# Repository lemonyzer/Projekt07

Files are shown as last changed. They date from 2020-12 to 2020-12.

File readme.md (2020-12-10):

# Playstation 2 Controller (Digital & Analog) am PIC16F84A 
## mit Zustandsausgabe über MAX7219 LED-Matrix 

### Videos
Projekt07 - PS2 Controller @ PIC16F84A with MAX7219 (https://www.youtube.com/embed/H5jBCrzZ8P4?mute=1;autoplay=1)
Projekt07 - PS2 Controller @ PIC16F84A (https://www.youtube.com/embed/TfXMUS_N8tY?mute=1;autoplay=1)

### PlayStation 2 Controller
<p>
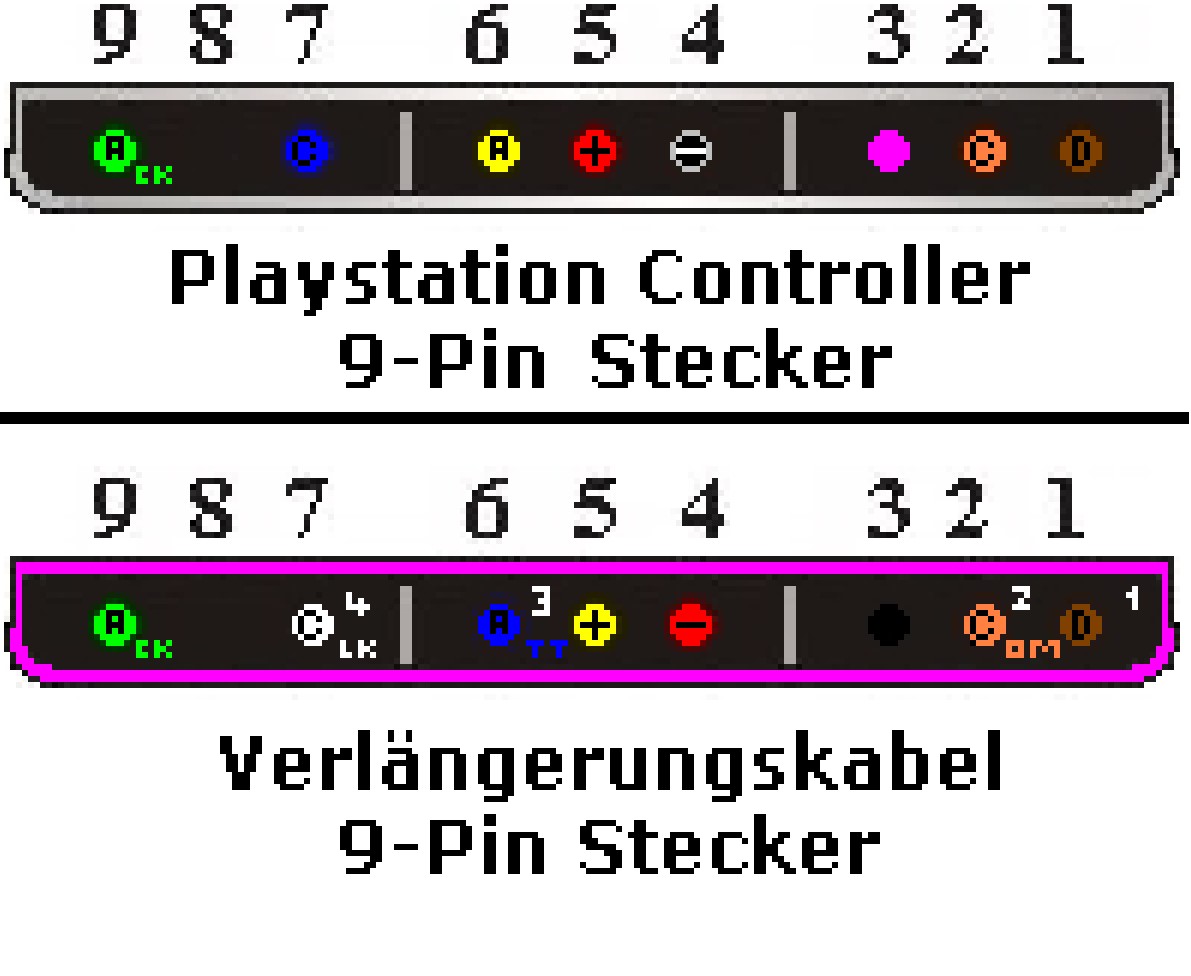
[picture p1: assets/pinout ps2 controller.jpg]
    <br><br>
    <ol>
        <li><p style="margin-bottom: 0cm; text-decoration: none;"><b><font color="#ff0000">(Ausgang)</font>	<font color="#00ff00">DATA</font></b>, 8-bit, serieller Transfer</p>
            <p style="margin-bottom: 0cm; text-decoration: none;">-bei negativer	Flanke von CLOCK</p></li>
        <li><p style="margin-bottom: 0cm; text-decoration: none;"><b><font color="#ff0000">(Eingang)</font>	<font color="#b3b3b3">COMMAND</font></b>, 8-bit, serieller Transfer</p>
            <p style="margin-bottom: 0cm; text-decoration: none;">-bei negativer	Flanke von CLOCK</p></li>
        <li><p style="margin-bottom: 0cm; text-decoration: none;"><i>Nicht	belegt</i></p></li>
        <li><p style="margin-bottom: 0cm; text-decoration: none;"><b>(Eingang)	<font color="#280099">GND</font> - </b>Pin an Masse</p></li>
        <li><p style="margin-bottom: 0cm; text-decoration: none;"><b>(Eingang)	<font color="#ffff00">VCC</font> - </b>Pin zur +5V Spannungsquelle</p></li>
        <li><p style="margin-bottom: 0cm; text-decoration: none;"><b><font color="#ff0000">(Eingang)</font>	<font color="#ff0000">ATT</font> -</b> bevor der Controller Daten	erhält, muss hier 0V (Masse) anliegen.</p></li>
        <li><p style="margin-bottom: 0cm; text-decoration: none;"><b><font color="#ff0000">(Eingang)</font>	CLOCK -</b> zur synchronisierten Übertragung</p></li>
        <li><p style="margin-bottom: 0cm; text-decoration: none;"><i>Nicht	belegt</i></p></li>
        <li><p style="margin-bottom: 0cm; text-decoration: none;"><b>(Ausgang)	<font color="#cc6633">ACK</font> - </b>sendet ein Signal, wenn ein	Befehl an Pin 2 angekommen ist</p></li>
    </ol>
    <p style="margin-bottom: 0cm; text-decoration: none;"><font color="#ff0000"><b>ROT</b><font color="#000000"> markierte Ein- oder Ausgänge sind direkt am PIC angeschlossen.</font></font></p>
    <p style="margin-bottom: 0cm; text-decoration: none;"><br></p>
</p>

### Schaltplan
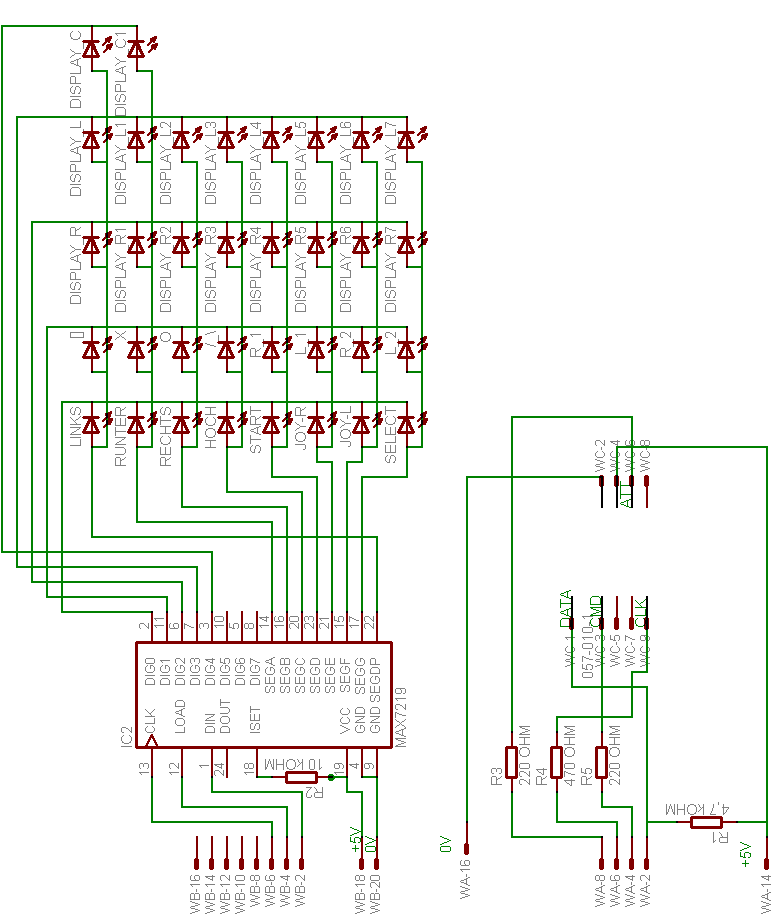
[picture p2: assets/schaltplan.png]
Schaltplan
   

### Platinen Layout
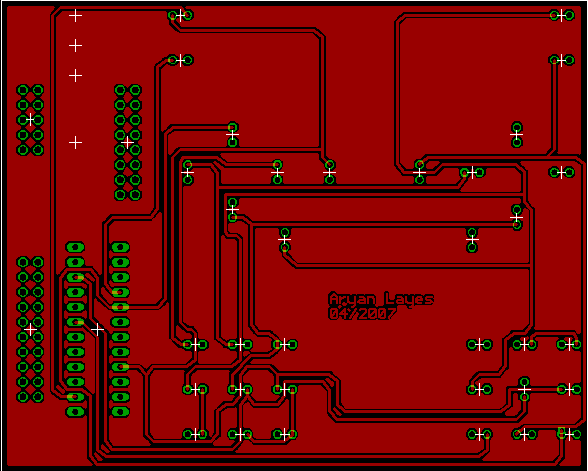
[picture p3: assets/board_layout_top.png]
Layout Top
   
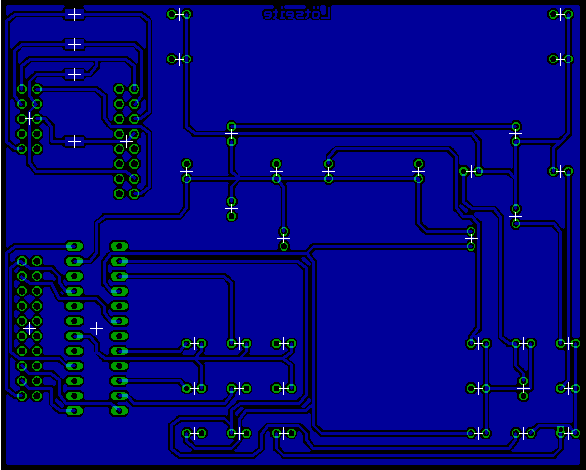
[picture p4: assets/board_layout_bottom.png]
Layout Bottom
   

### Bestückungsplan
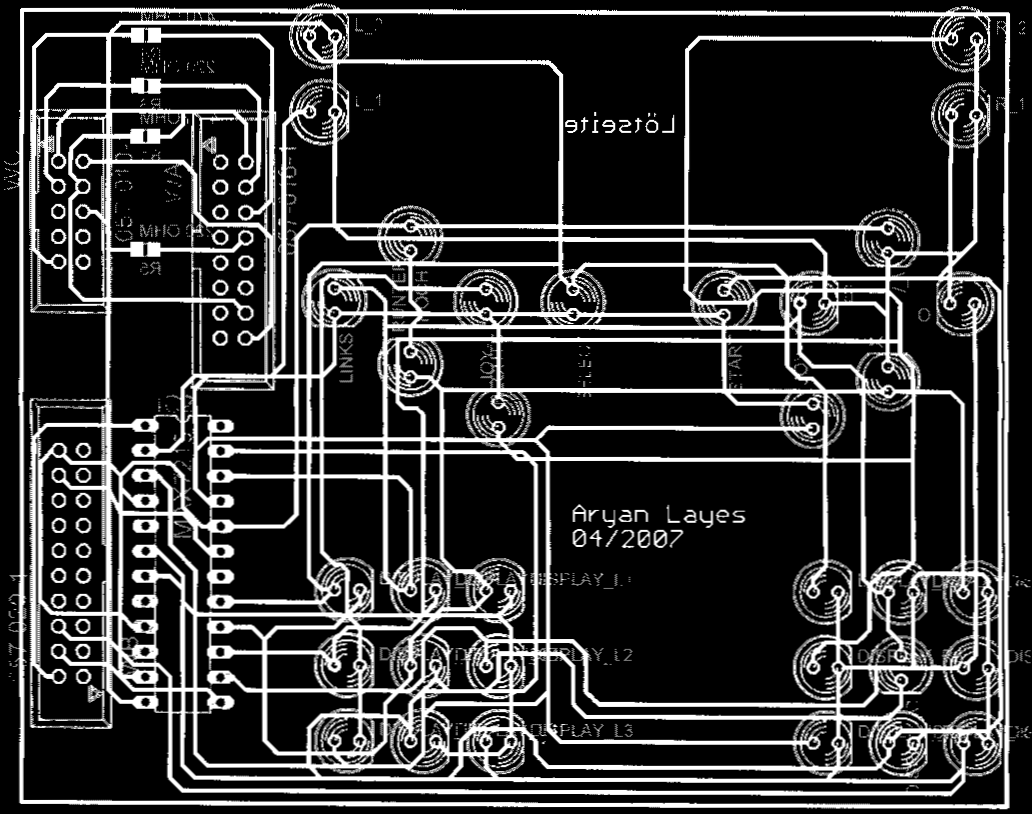
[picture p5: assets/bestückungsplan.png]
Bestückungsplan
   

### Flowcharts
<details> 
  <summary>V5: Flowcharts aus der Dokumentation </summary>
   <p>
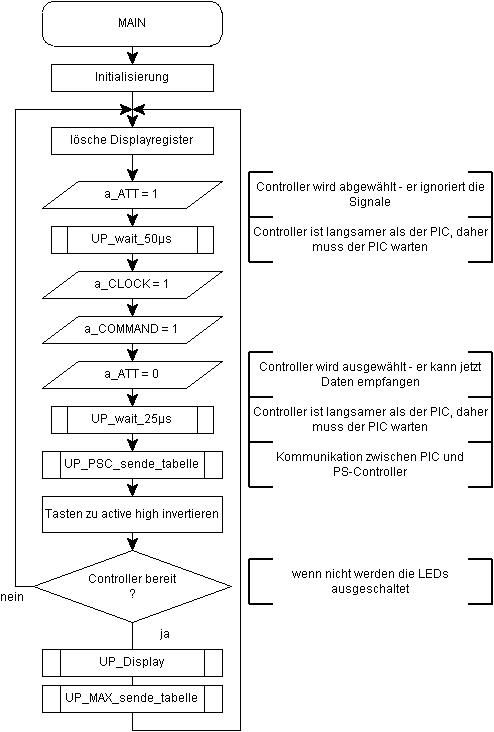
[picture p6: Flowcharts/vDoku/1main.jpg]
         
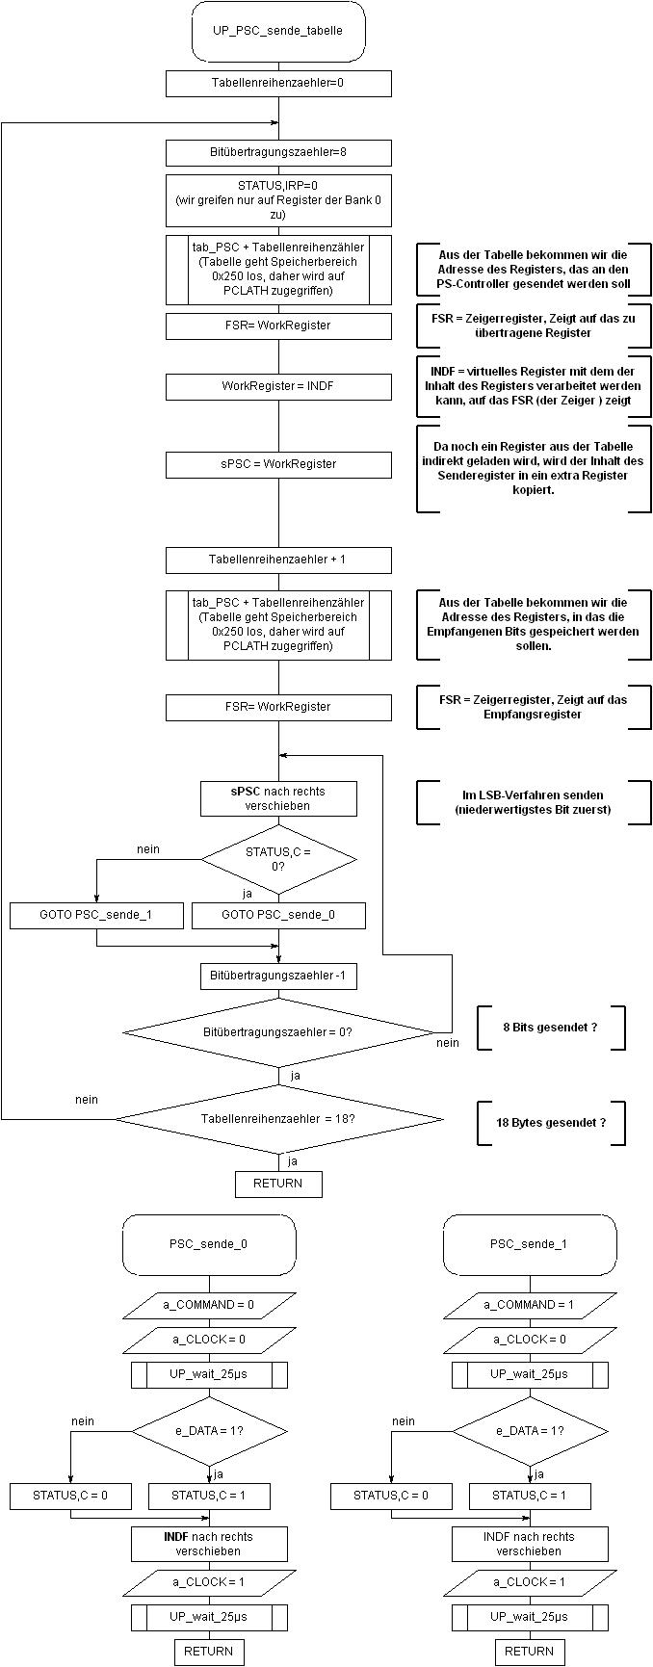
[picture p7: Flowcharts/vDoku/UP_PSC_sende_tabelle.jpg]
         
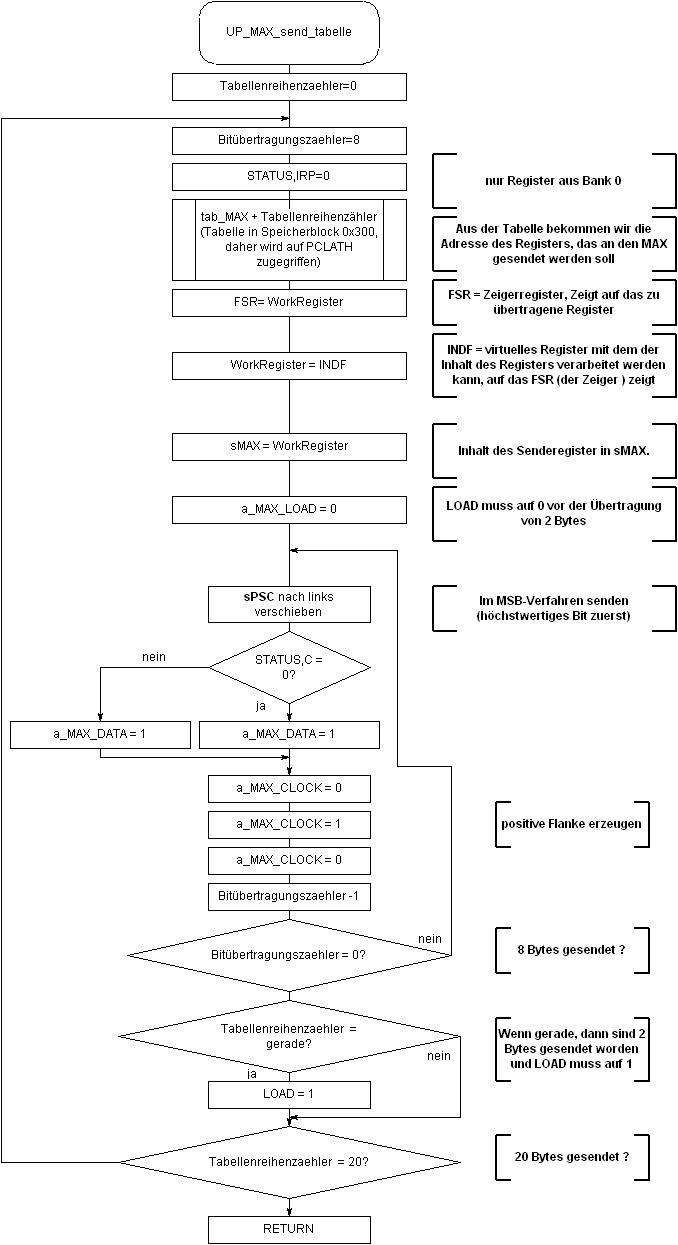
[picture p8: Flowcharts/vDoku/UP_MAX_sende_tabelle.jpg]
         
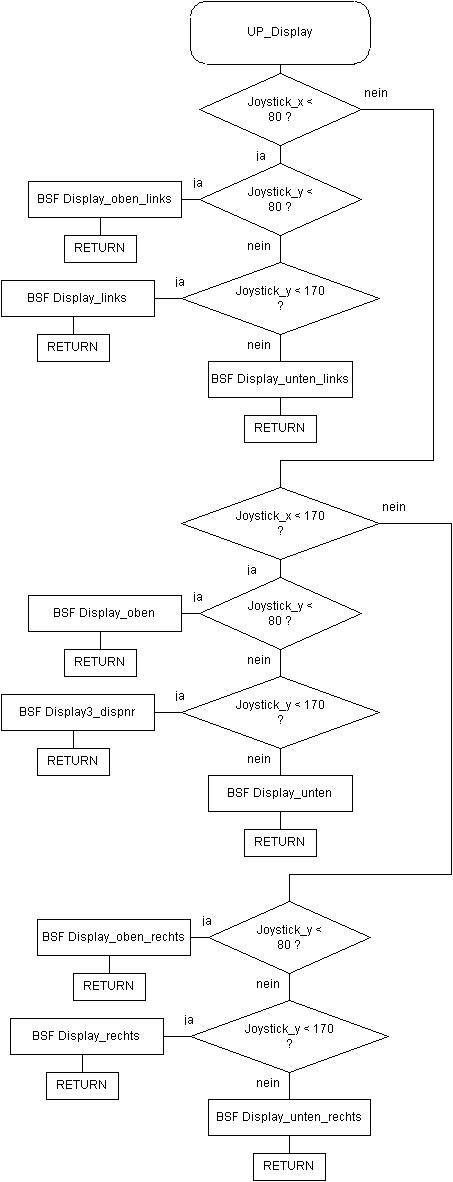
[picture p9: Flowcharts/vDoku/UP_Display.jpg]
         
    </p>
</details>

<details> 
  <summary>V4: Flowcharts </summary>
   <p>
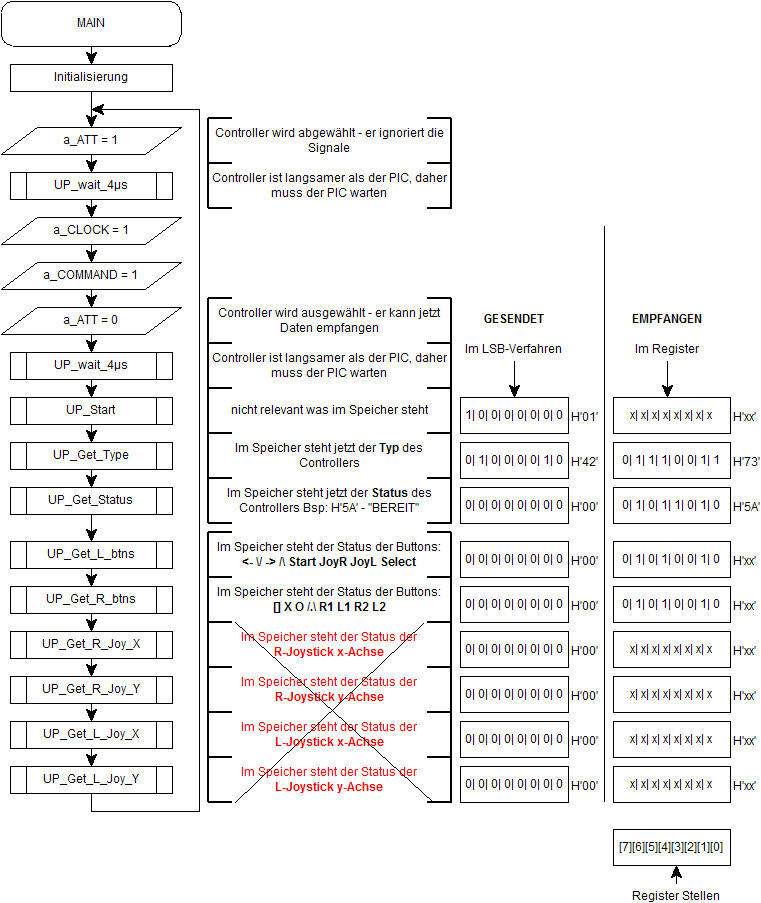
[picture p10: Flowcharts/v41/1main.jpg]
         
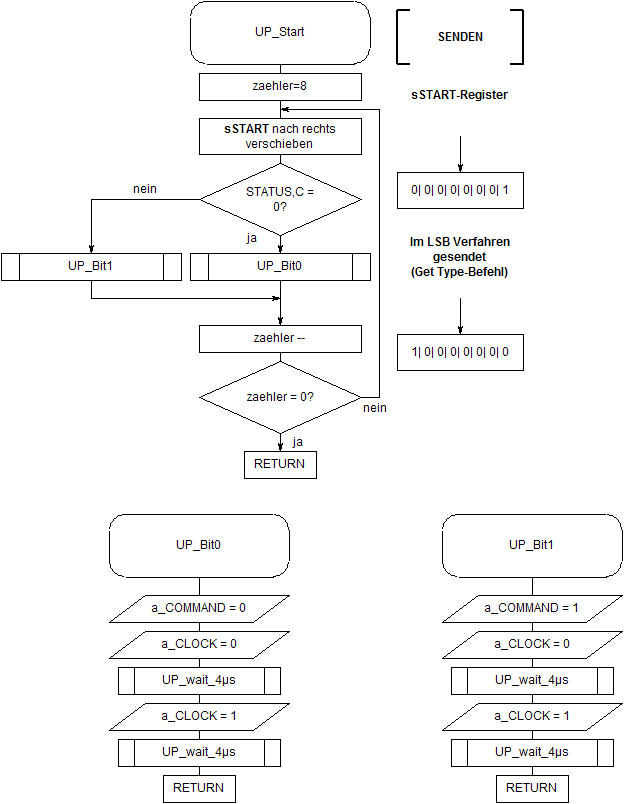
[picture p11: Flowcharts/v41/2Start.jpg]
         
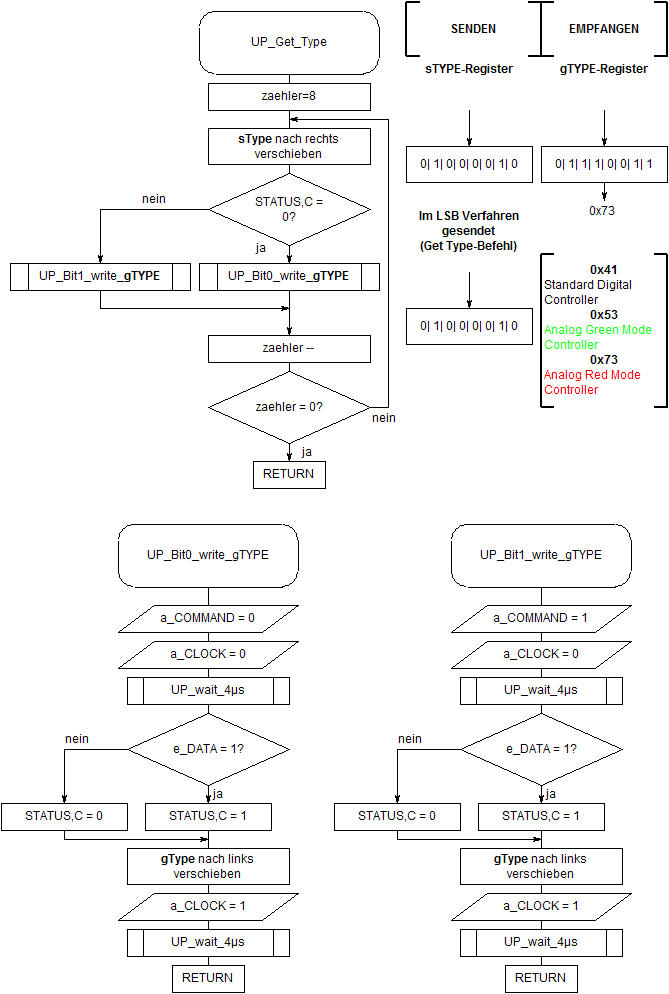
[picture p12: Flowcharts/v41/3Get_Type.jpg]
         
         
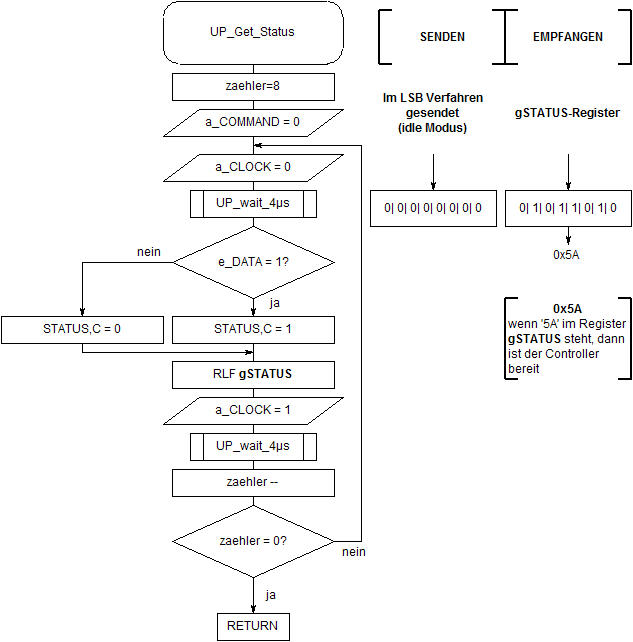
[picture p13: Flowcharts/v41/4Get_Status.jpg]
         
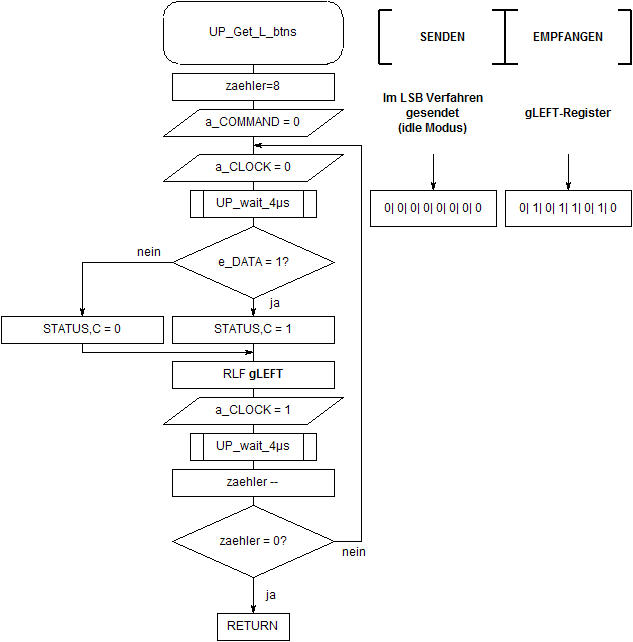
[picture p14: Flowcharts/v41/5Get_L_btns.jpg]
         
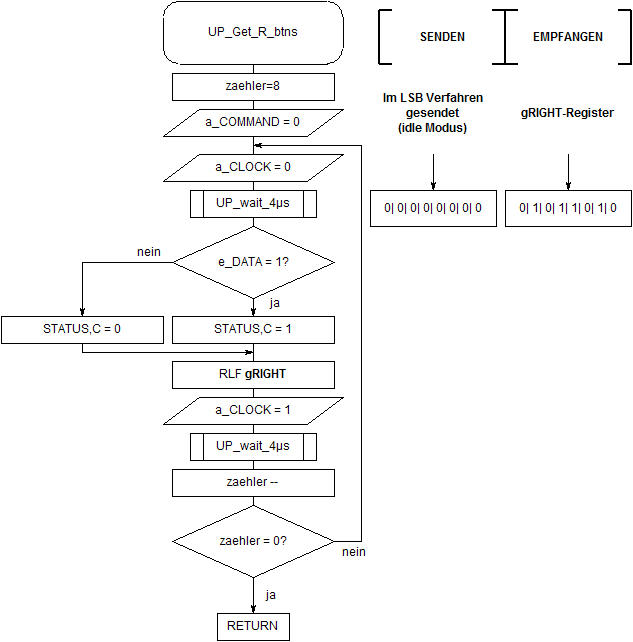
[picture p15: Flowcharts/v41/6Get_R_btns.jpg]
         
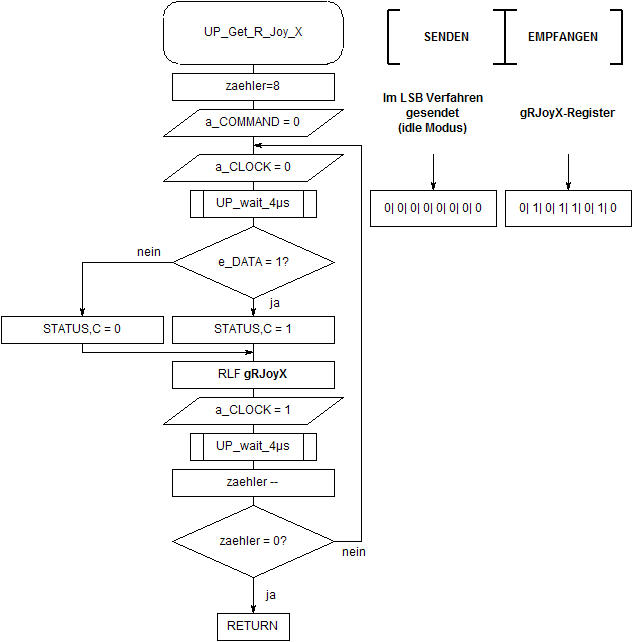
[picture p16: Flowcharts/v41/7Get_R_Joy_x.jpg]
         
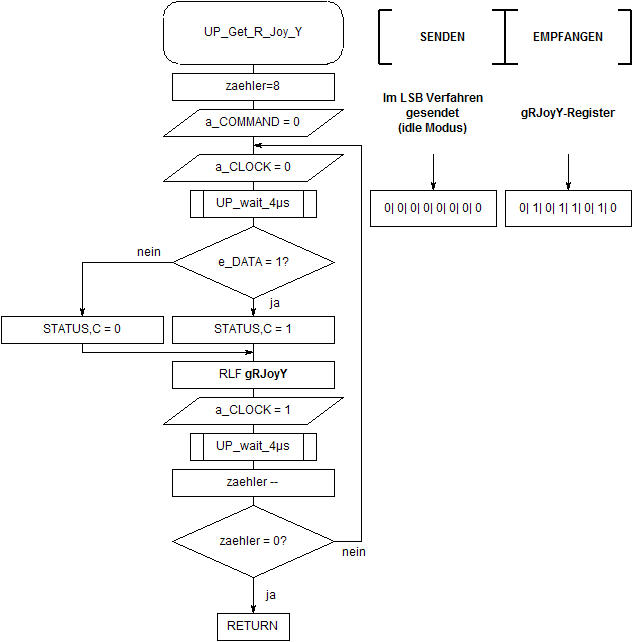
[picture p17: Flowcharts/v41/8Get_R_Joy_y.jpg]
         
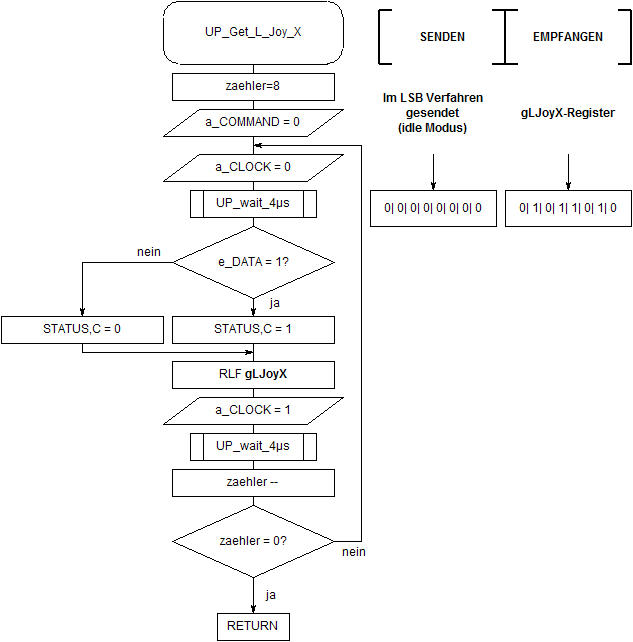
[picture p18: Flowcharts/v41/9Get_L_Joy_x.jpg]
         
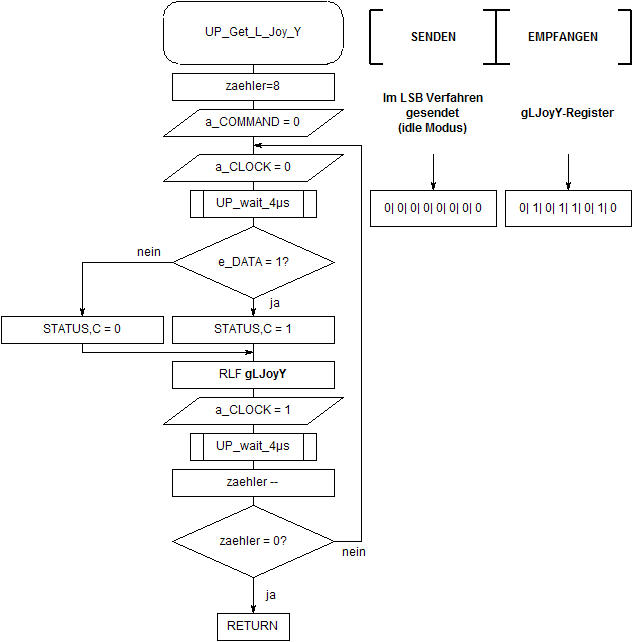
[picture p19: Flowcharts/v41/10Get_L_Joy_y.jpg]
        
    </p>
</details>

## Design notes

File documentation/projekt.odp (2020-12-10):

## Abschlussprojekt - ATINF

Aryan Layes

## Projekt

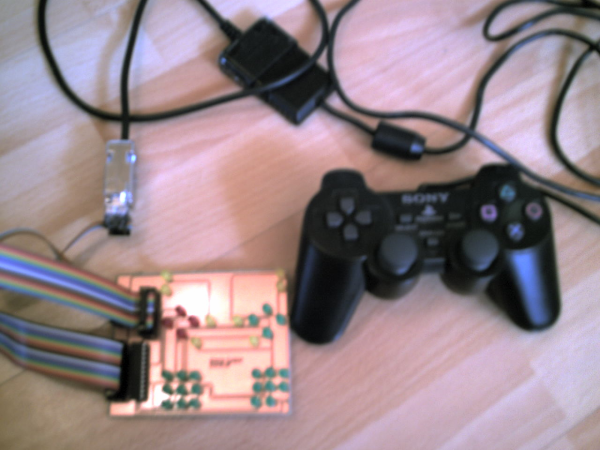
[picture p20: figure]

## Projektbeschreibung

- Der PS-Controller ist an PORTA des PIC's angeschlossen
- Der PIC fragt die Zustände des Controller's ab
- Ausgabe Variante 1:
  - Die Abgefragten Zustände werden über 8 LED's an PORTB ausgegeben
- Ausgabe Variante 2:
  - Die Abgefragten Zustände werden über einen MAX7219 LED Display Treiber ausgegeben

## PS-Controller Schnittstelle

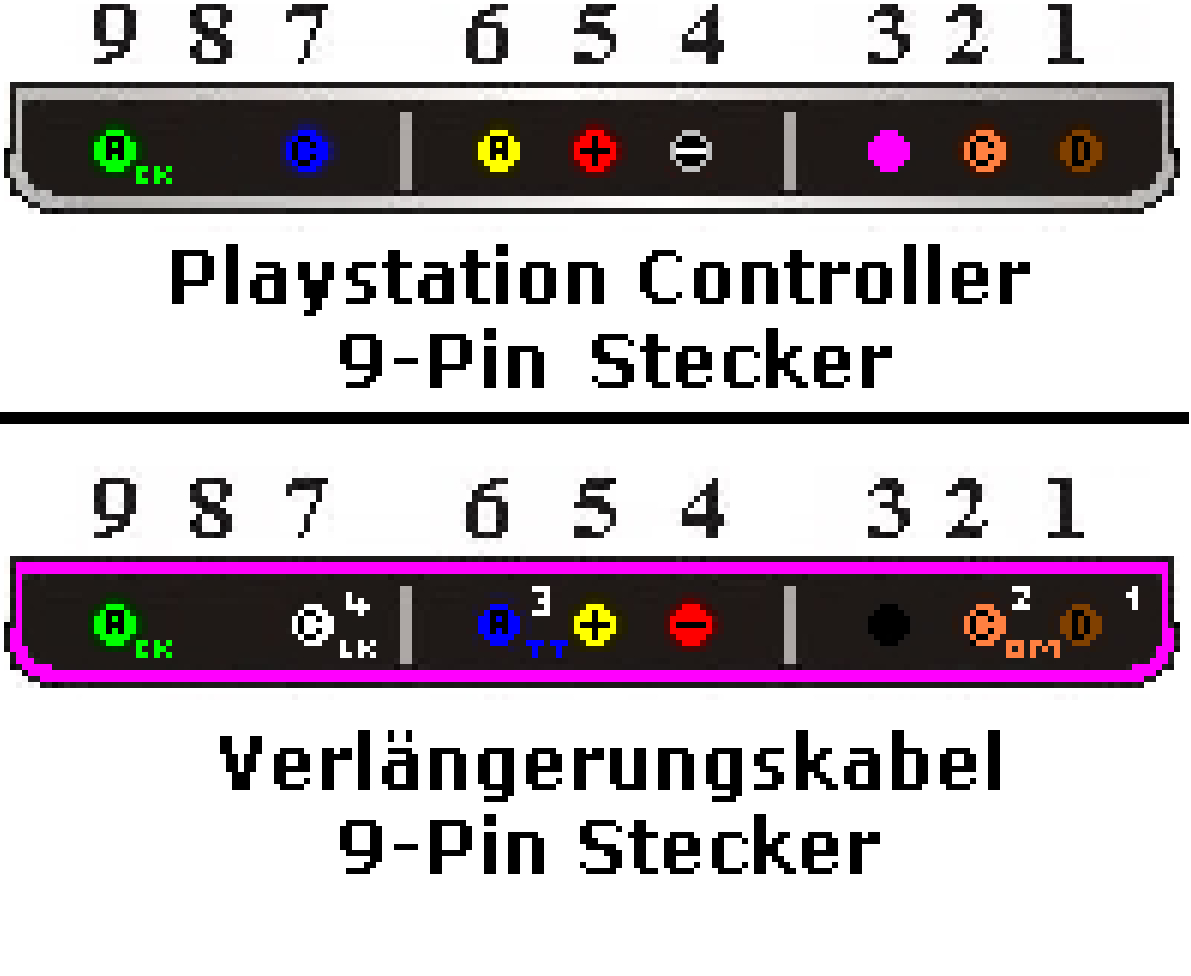
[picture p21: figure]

- 1. (Ausgang) DATA, serielle Datenübertragung - bei negativer Flanke von CLOCK sendet der Controller ein Bit über die DATA Leitung - die Datenübertragung beginnt mit dem niederwertigsten Bit ( LSB-Verfahren ).
- 2. (Eingang) COMMAND, serielle Datenübertragung - bei negativer Flanke von CLOCK ließt der Controller das Bit auf der COMMAND Leitung
- 3. Nicht belegt

## PS-Controller Schnittstelle

- 4. (Eingang) GND - Pin an Masse
- 5. (Eingang) VCC - Pin zur +5V Spannungsquelle
- 6. (Eingang) ATT - bevor der Controller Daten erhält, muss hier 0V (Masse) anliegen.
- 7. (Eingang) CLOCK - zur synchronisierten Übertragung
- 8. Nicht belegt
- 9. (Ausgang) ACK - sendet ein Signal, wenn ein Byte über COMMAND angekommen ist

## PS-Controller Kommunikation

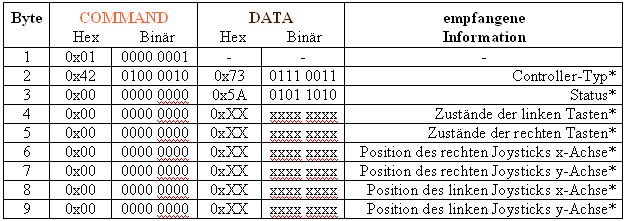
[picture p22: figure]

## Controller-Typ

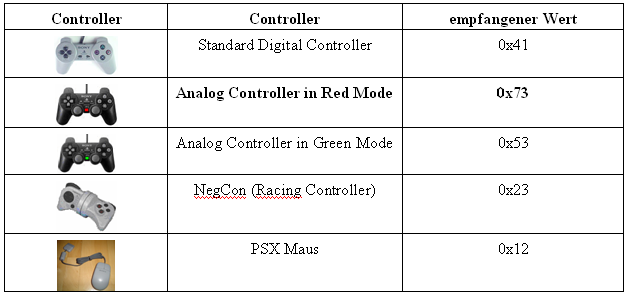
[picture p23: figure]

## Status

- Wenn das empfangene Byte ungleich 01011010 ist, ist der Controller nicht bereit oder sogar defekt! Die Zustände der Tasten, die in der folgenden Übertragung empfangen werden, sind wahrscheinlich unbrauchbar.

## Zustände der Tasten

- Allgemeines zum Zustand der Tasten:
- Wenn eine Taste gedrückt ist, sendet der Controller an der Stelle eine 0. Im englischen heißt das, dass die Tasten „active low“ sind !
- *linke Tasten
- Zu den linken Tasten gehören:
- Die Zustände der gelb markierten Tasten sind bei einem Standart Digital Controller, der keine Joysticks hat, immer auf 1.
- *rechte Tasten
- Zu den rechten Tasten gehören:

## MAX7219 – LED Display Treiber Ein- und Ausgänge

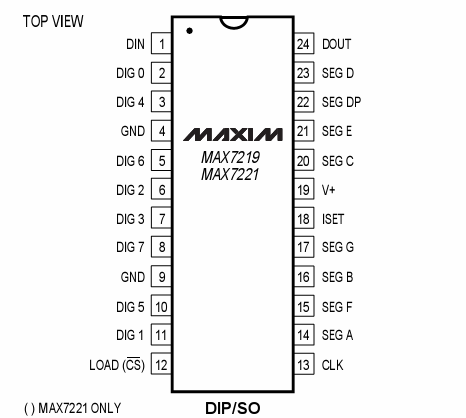
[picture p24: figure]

- Spannungs- und Stromversorgung
- 19. V+ (+5V) Spannungsquelle
- 4 & 9. GND
- 5. ISET Helligkeitsregelung der LED Anzeige über extern geschalteter Widerstand.

## MAX7219 – LED Display Treiber Ein- und Ausgänge

- I/O Kommunikation/Steuerung des MAX-IC’s
- 1. (Eingang) DIN, serielle Datenübertragung
- - die Datenübertragung beginnt mit dem letzten Bit 15 ( MSB-Verfahren ). - bei positiver Flanke von CLK übernimmt der MAXIM das anstehende Bit an DIN.
- 12. (Eingang) LOAD - die Übertragung beginnt mit dem Schalten von LOAD auf 0V (Masse). Die zwei Bytes werden transferiert und danach wird LOAD wieder auf 1(+5V) geschaltet.
- 13. (Eingang) CLK - zur synchronisierten Übertragung der Bits über DIN

## MAX7219 – LED Display Treiber Ein- und Ausgänge

- LED Steuerung
- 6. (Ausgang) DIG 0 bis DIG 7 – Jede LED wird über dazugehörigen Digitausgang angesteuert, dies geschieht über die Kathoden der LEDs
- 7. (Ausgang) SEG DP - G – Die einzelnen Segmente der Digits werden mit den gleichen Segmenten der anderen Digits verbunden. Zum Beispiel: Anode der SEG DP LED an im Digit 0 ist verbunden mit der Anode der SEG DP LED im Digit 1.

## MAX7219 Steuerung

- Die Steuerung des MAX7219 erfolgt über zwei Byte lange Befehle.
- Das zweite Byte (links) gibt an auf welches Register des MAX7219 zugegriffen wird. Mit dem ersten Byte (rechts) werden die Werte in dem Register festgelegt.
- Die folgende Tabelle aus dem Datenblatt des MAX7219 zeigt welche Register zur Verfügung stehen.

## MAX7219 Steuerung

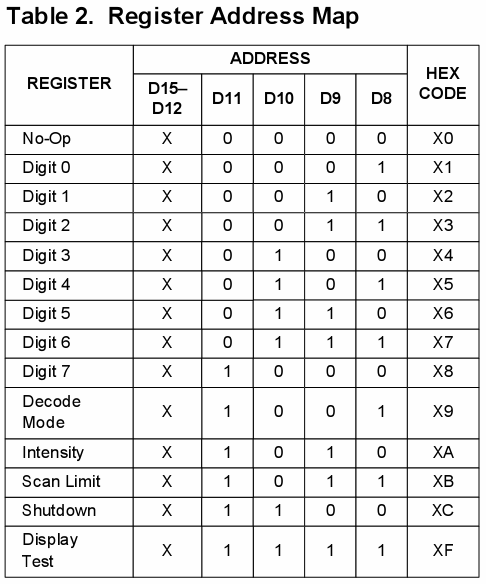
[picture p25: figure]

## MAX7219 Register

- Digit 0-7:
- speichert die Zustände der Segmente
- Decode Mode:
- Der MAX7219 wurde so entwickelt, dass er neben der ganz normalen Ausgabe der Digits einen integrierten BCD-Decoder bereitstellt. Auf diesen werde ich in meiner Dokumentation aber nicht eingehen.
- Intensity:
- Auch hier gibt es eine spezielle Funktion des Display Treibers. Die Helligkeitssteuerung kann über den ISET-Eingang, oder durch dieses Register erfolgen. Da ich in meinem Projekt keine Helligkeitssteuerung verwende und das Datenblatt die Informationen zu diesem Feature beinhaltet, gehe ich nicht näher darauf ein.

## MAX7219 Register

- Scan Limit:
- Über dieses Register lässt sich einstellen wie viele Digits genutzt werden. Nicht benutzte Digits sollten nicht aktiviert werden, da diese die Helligkeit der Anzeige „dimmen“ würden.
- Shutdown:
- Mit diesem Register wird die Anzeige ein- und ausgeschaltet.
- Shutdown:
- Mit diesem Register kann die Anzeige geprüft werden. Im Testmodus sollten alle LEDs an sein.

## Flussdiagramme

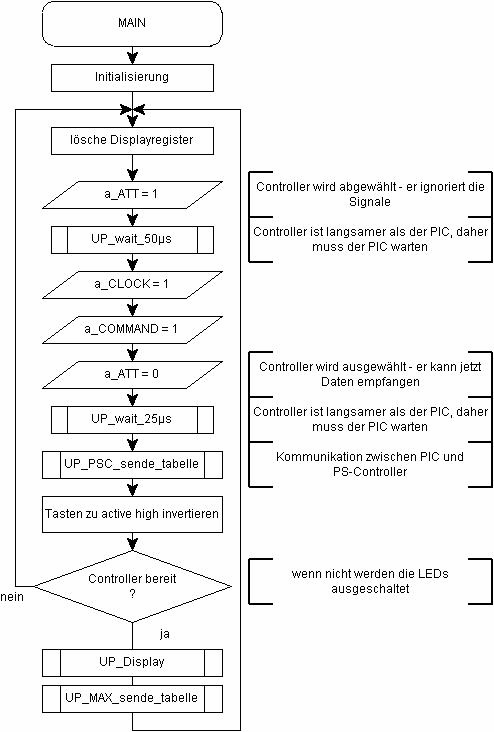
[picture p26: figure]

- Main

## Flussdiagramme

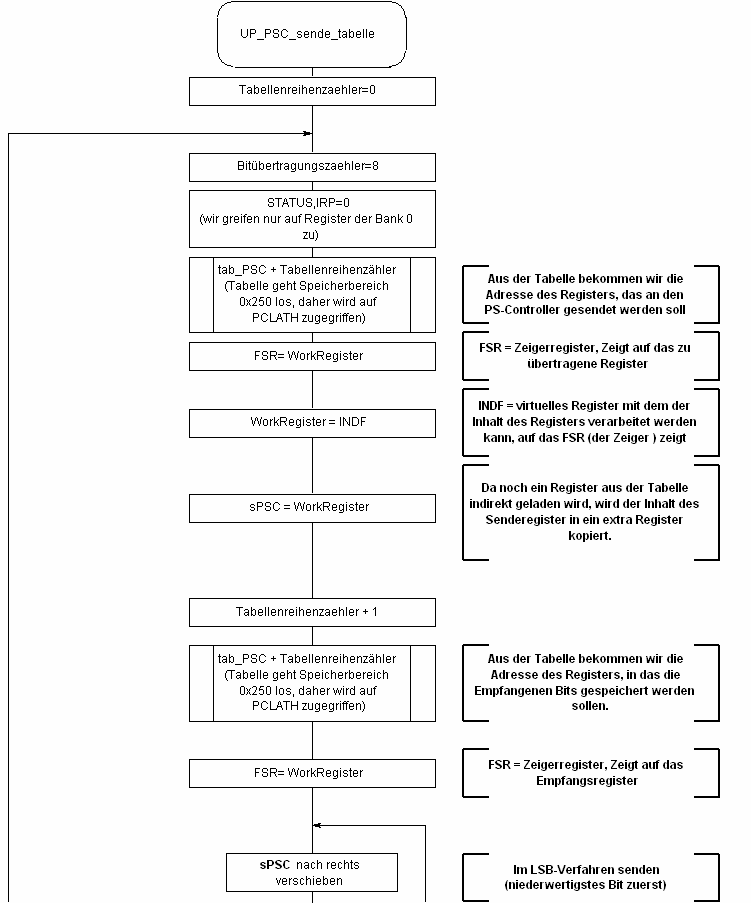
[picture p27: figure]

- UP_PSC_sende_tabelle Teil 1

## Flussdiagramme

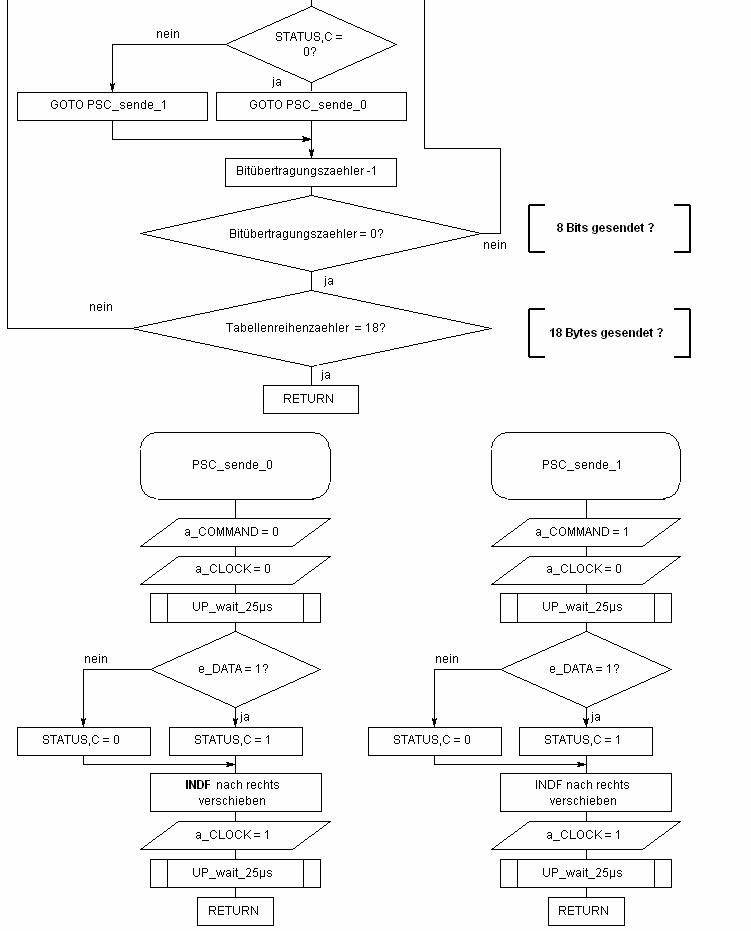
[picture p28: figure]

- UP_PSC_sende_tabelle Teil 2

## Flussdiagramme

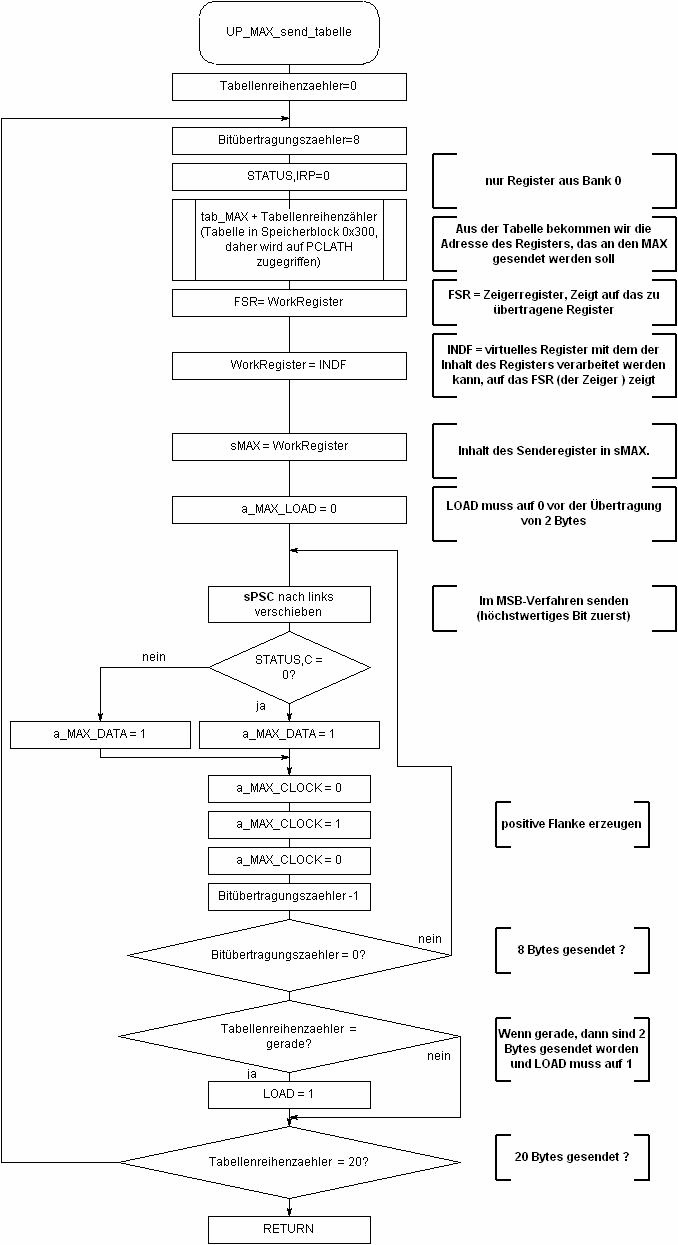
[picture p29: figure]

- UP_MAX_sende_tabelle

## Flussdiagramme

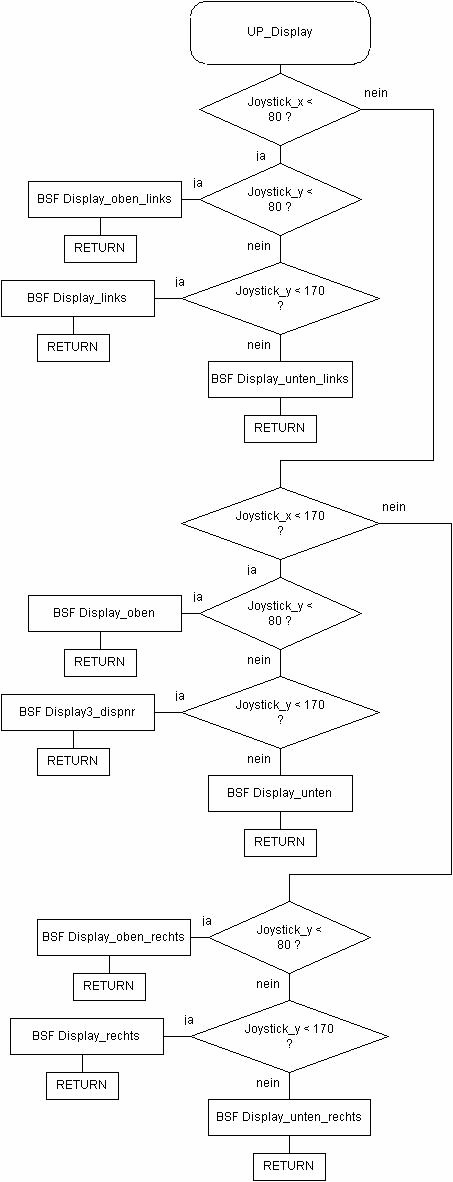
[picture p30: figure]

- UP_Display

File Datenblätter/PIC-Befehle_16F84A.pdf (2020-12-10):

Kurzübersicht über die Assemblerbefehle des PIC16F84A

Sprungbefehle und die Operationen mit Konstanten
ANDLW | k | UND-Verknüpfung des W-Registers mit einer Konstanten
CALL | k | Unterprogrammaufruf
CLRWDT | | Watch-Dog-Timer zurücksetzen
GOTO | k | Sprung zur angegebenen Position im Programm
IORLW | k | ODER-Verknüpfung des W-Registers mit einer Konstanten
MOVLW | k | W-Register mit einer Konstanten laden
RETURN | | Rücksprung aus dem Unterprogramm
RETLW | k | Rücksprung aus dem Unterprogramm mit Konstantenübergabe im W-
| | Register
SLEEP | | Standby-Modus einschalten
XORLW | k | Exklusiv-ODER-Verknüpfung des W-Registers mit einer Konstanten

byteorientierte Befehle
ADDWF | f, d | Addiere W-Register zu einem Register
ANDWF | f, d | UND-Verknüpfung zwischen dem W-Register und einem anderem
| | Register
CLRF | f | Lösche Register
CLRW | | Lösche W-Register
COMF | f, d | Bilde Komplement des Registers
DECF | f, d | Dekrementiere Register
DECFSZ | f, d | Dekrementiere Register und springe bei Null
INCF | f, d | Inkrementiere Register
INCFSZ | f, d | Inkrementiere Register und springe bei Null
IORWF | f, d | ODER-Verknüpfung zwischen W-Register und Register
MOVF | f, d | Registerinhalt kopieren
MOVWF | f, d | W-Register nach Register kopieren
NOP | | Keine Operation
RLF | f, d | Rotiere Register nach links durch Carry-Flag
RRF | f, d | Rotiere Register nach rechts durch Carry-Flag
SUBWF | f, d | Subtrahiere W-Register von Register
SWAPF | f, d | Tausche Bytehälften vom Register
XORWF | f, d | Exklusiv-ODER-Verknüpfung von W-Register und Register

bitorientierte Befehle
BCF | f, b | lösche Bit des Registers
BSF | f, b | setze Bit des Registers
BTFSC | f, b | teste Bit des Registers uns springe wenn gelöscht
BTFSS | f, b | teste Bit des Registers und springe wenn gesetzt
k | Konstante: Wert binär (B'xxxxxxxx'), hexadezimal (H'xx') oder dezimal (D'xx')
f | (symbolische) Adresse des Registers, in dem sich der Operand befindet
d=W | Ergebnis der Operation wird im Arbeitsregister gespeichert
d=F | Ergebnis der Operation wird im Operandenregister gespeichert
b | Nummer des Bits (0-7)

Einige wichtige Register:
Bank 0
TMR0 | 8-bit Real-Time Clock/Counter
PCL | Low Order 8 bits of the Program Counter (PC)
STATUS | IRP | RP1 | RP0 | TO | PD | Z | DC | C
PORTA | - | - | - | RA4/T0CKI | RA3 | RA2 | RA1 | RA0
PORTB | RB7 | RB6 | RB5 | RB4 | RB3 | RB2 | RB1 | RB0
INTCON | GIE | EEIE | T0IE | INTE | RBIE | T0IF | INTF | RBIF
Bank 1
OPTION_REG | RBPU | INTEDG | T0CS | T0SE | PSA | PS2 | PS1 | PS0
TRISA | - | - | - | PORTA Data Direction Register
TRISB | PORTB Data Direction Register

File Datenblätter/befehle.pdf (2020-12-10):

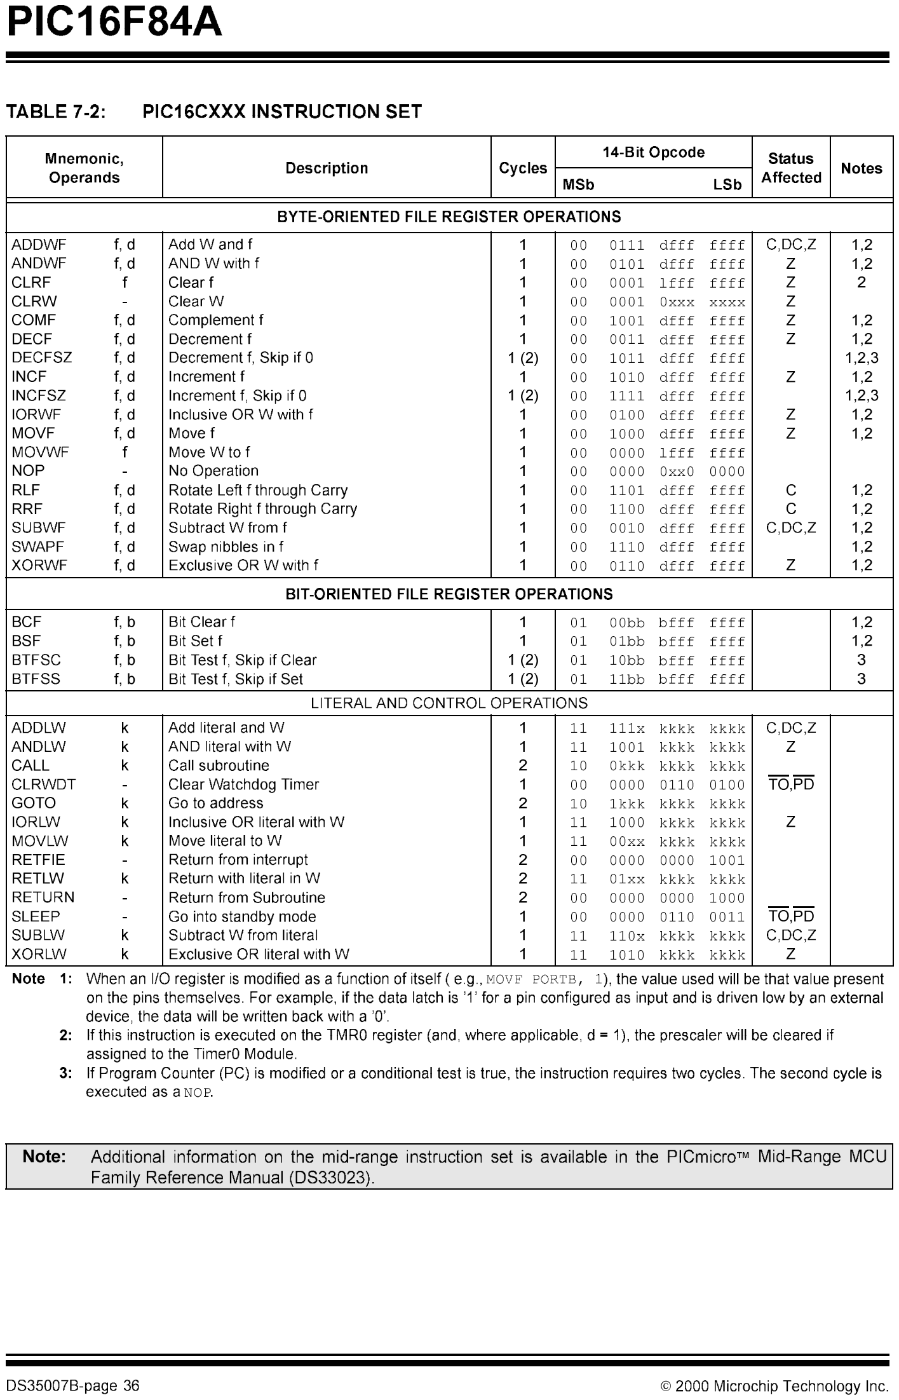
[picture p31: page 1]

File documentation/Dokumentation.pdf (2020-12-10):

## Abschlussprojekt

## „Arbeitsmethoden der technischen Informatik“

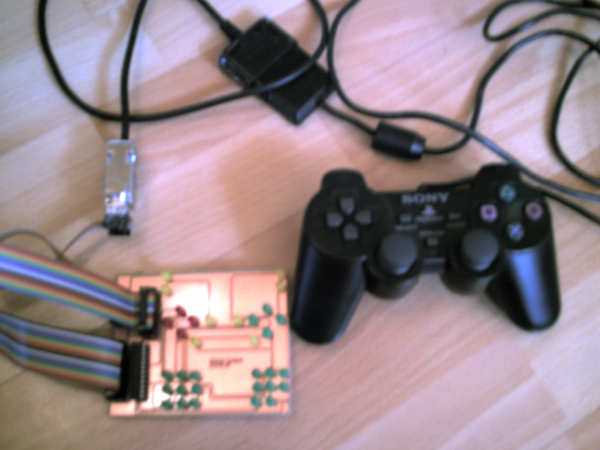
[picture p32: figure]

## Playstation 2 Controller (Digital & Analog) am PIC16F84A mit Zustandsausgabe über MAX7219

## von Aryan Layes

## Inhaltsverzeichnis

## Einleitung

## 1.0 Projektvorgaben 1.1 Projektbeschreibung 1.2 Ziel des Projekts

## Hardware

## 2.0 Schaltplan des PS2-MAX-Boards 2.1 Bestückung / Stückliste 2.2 Die Schnittstelle des Playstation Controllers 2.3 Kommunikations-Protokoll des Playstation Controllers 2.4 MAX7219 I/O 2.5 MAX7219 Steuerung

## Software

## 3.0 Neue Programmiermethoden 3.1 Quellcode 3.2 Flussdiagramme

## Bilanz

## 4.0 Eigene Erfahrungen

## Anhang

## 5.0 Quellen 5.1 Versicherung der Eigenleistung

µC-Projekt | Arbeitmethoden der Informatik | Seite 1 von 35
Aryan Layes | www.Projekt07.dl.am | HBFI05a

## 1.0 Projektvorgaben

Im Fach „Arbeitsmethoden der technischen Informatik“ war es unsere Aufgabe, ein Projekt mit Hilfe der im Unterricht angefertigten PIC-Platine anzufertigen. Es wurden mehrere Projektvorschläge angeboten die mir alle nicht zusagten. Zu erst wollte ich einen eigenen Controller mit Hilfe eines alten PS-Controllers entwickeln, doch Herr Glaser überredete mich den Controller funktionstüchtig zu lassen und mein Projekt auf das

auslesen des Controller mit einer einfachen Anzeige zu beschränken.

### Zeitliche Vorgaben: Für das gesamte Projekt ist ein Zeitrahmen von dem Tag der Projektgenehmigung bis

zum 19.04.07 vorgesehen.

## 1.1 Projektbeschreibung

### Mein Projekt besteht aus der PIC-Platine (bestückt mit einem PIC16F84A), einem

Playstation Controller und einem MAX7219 LED Display Treiber von MAXIM.

### Der Playstation Controller ist über den Wannenstecker SV1 mit dem PIC an PORTA

verbunden.

### Der MAX 7219 Baustein ist über den Wannenstecker SV2 mit dem PIC an PORTB

verbunden.

### Der PIC kommuniziert mit dem PS-Controller und erhält so die Zustände der Tasten und Joysticks. Nachdem er diese Daten erhalten hat, überträgt er sie an den MAX7219

Display Treiber, aus dem Hause MAXIM, um die Zustände anzeigen zu lassen.

## 1.2 Ziel des Projekts

Mein Projekt hat in erster Linie nur das Ziel zu verstehen, wie man mit einem Playstation-Controller kommuniziert um die Zustände der Tasten und Joysticks herauszufinden. Die Zustandsanzeige der Tasten und Joysticks über den MAX-Baustein ist nur durch eigene Interesse und Neugier entstanden. Auf diesem Wissen lassen sich jetzt viele Projekte aufbauen, z.B. ein „kabelloser“ Controller oder das Steuern eines

Roboters mit dem PS-Controller.

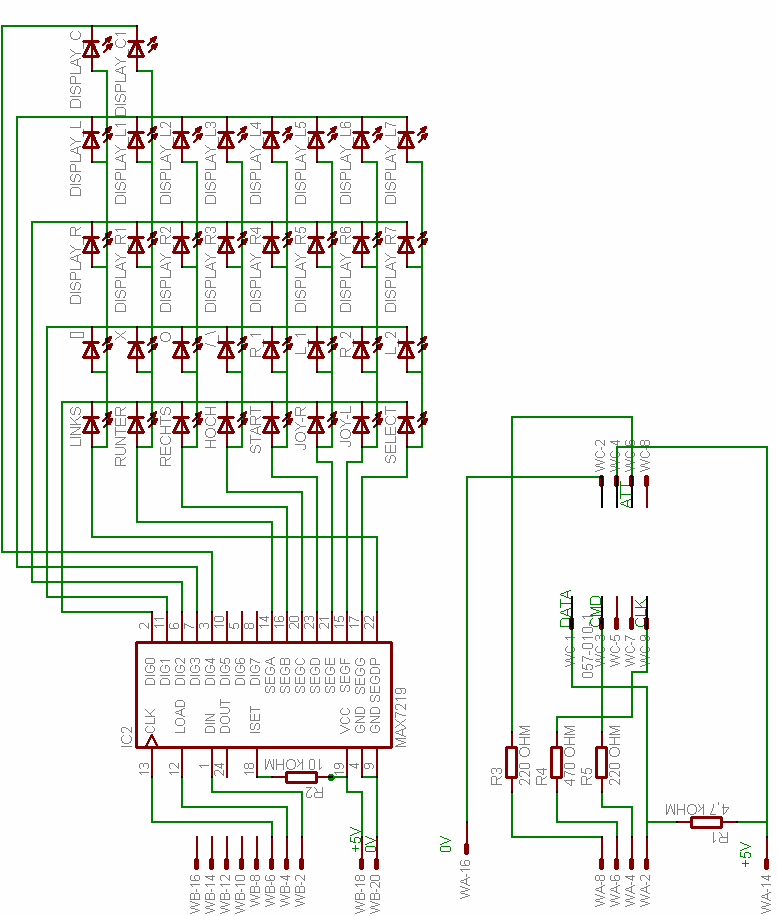
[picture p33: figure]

Aryan Layes | www.Projekt07.dl.am | HBFI05a

## 2.0 Schaltplan des PS2-MAX-Boards

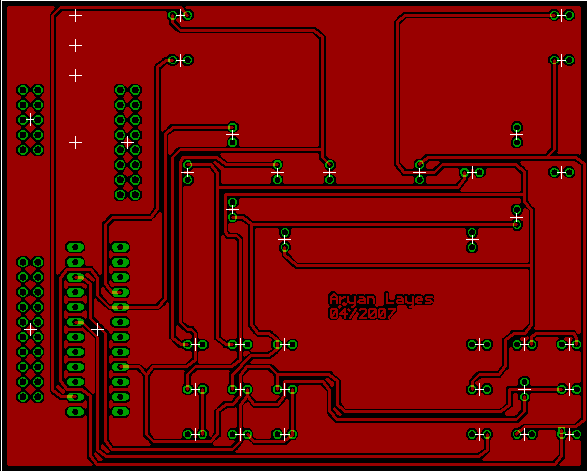
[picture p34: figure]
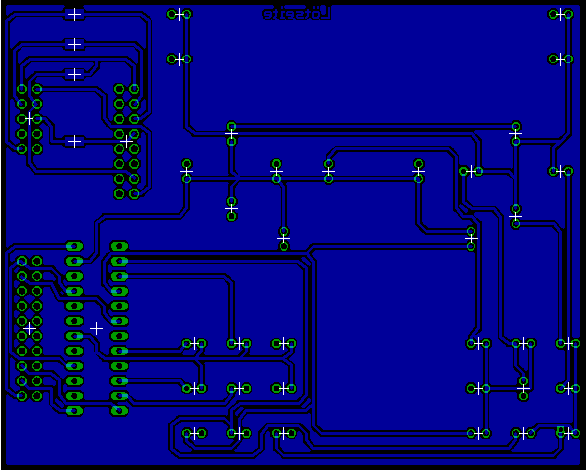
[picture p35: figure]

Aryan Layes | www.Projekt07.dl.am | HBFI05a

## Vorderseite des PSC-MAX-Boards

## Rückseite und damit Lötseite des PSC-MAX-Boards

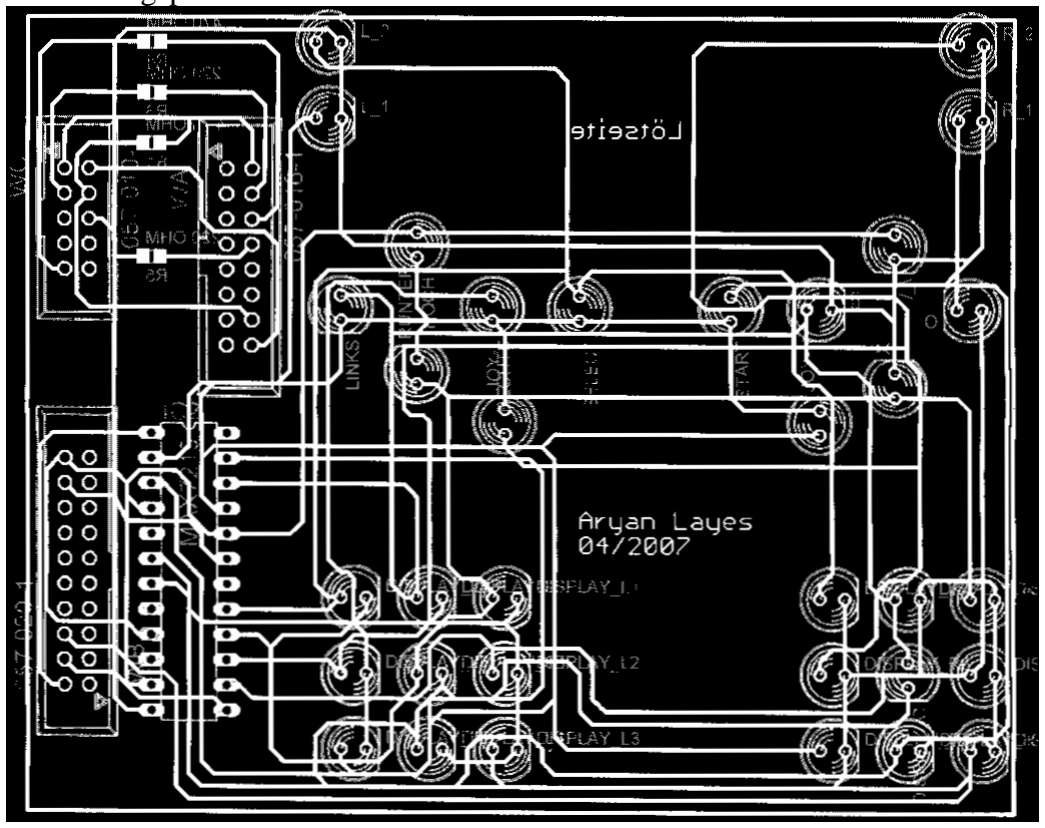
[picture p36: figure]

Aryan Layes | www.Projekt07.dl.am | HBFI05a

## 2.1 Bestückung / Stückliste

Bauteil | Wert
alle LED’s | besitzen einen integrierter Vorwiderstand, der für eine Spannung von 5 Volt vorgesehen ist
R1 | 4,7 kOHM
R2 | 10 kOHM
R3,R5 | 220 OHM
R4 | 470 OHM
R6 | 10 kOHM
IC2 | MAX 7219

## Bestückungsplan

### - In der Schaltung kommen vier verschiedene Widerstandswerte vor:

220 OHM | ROT ROT BRAUN | GOLD
470 OHM | GELB VIOLETT SCHWARZ SCHWARZ | GOLD
4,7 kOHM | GELB VIOLETT SCHWARZ BRAUN | GOLD
10 kOHM | BRAUN SCHWARZ ORANGE | GOLD

Aryan Layes | www.Projekt07.dl.am | HBFI05a
- Beim einsetzten des IC-Sockel (24 Pins) auf die Beinchen achten,

### da sie leicht beschädigt werden können!

### - Bei den Wannenstecker auf die Richtung achten!

### - Bei den LEDs auf die Polung achten! In einem Digit sind die Kathoden (flache Seite) miteinander verbunden. Die Anoden gehen an die

entsprechenden Segmente.

### Nur noch den MAX7219 vorsichtig auf den Sockel drücken und der Hardwareaufbau ist

erledigt.

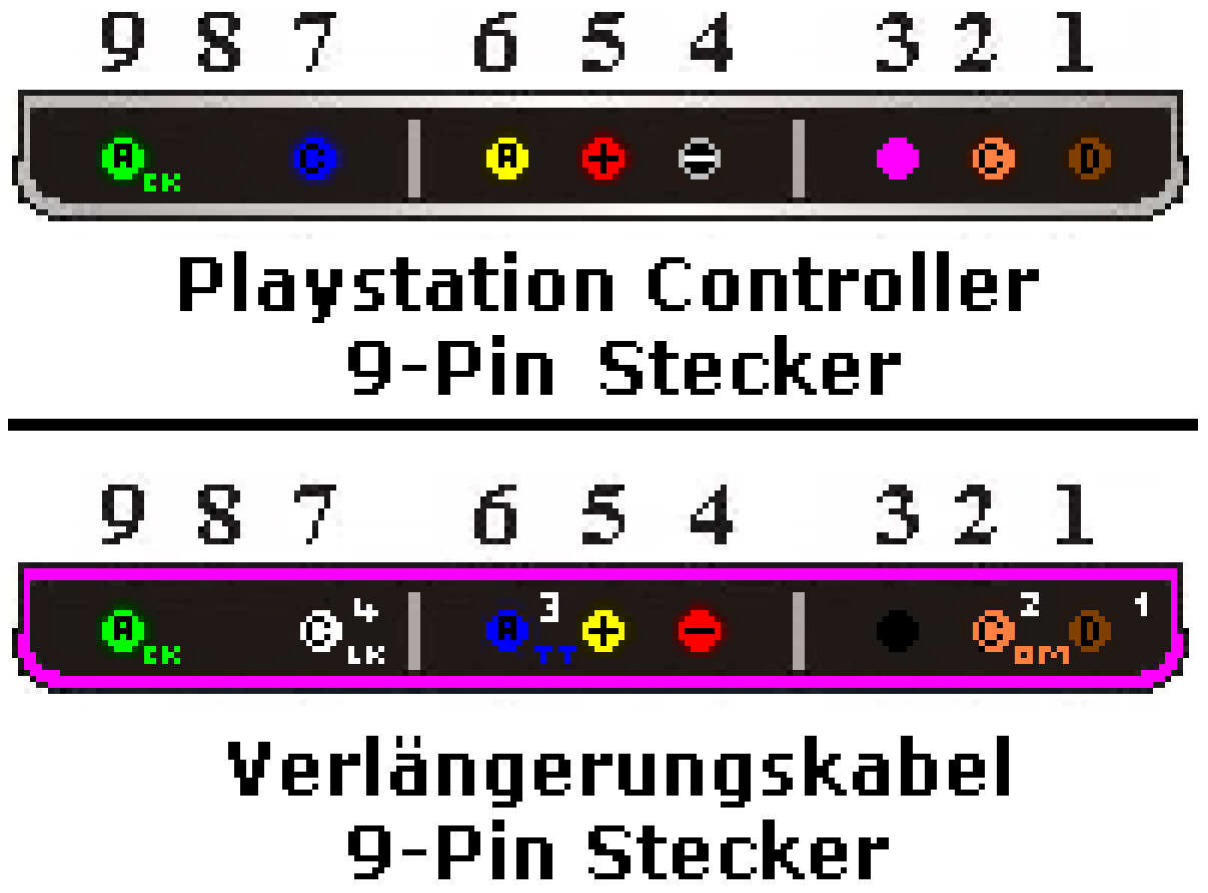
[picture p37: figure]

Aryan Layes | www.Projekt07.dl.am | HBFI05a

## 2.2 Die Schnittstelle des Playstation Controllers

Das wohl größte Problem in meinem Projekt lag an dieser Schnittstelle! In den ersten Wochen

### der Projektphase verwendete ich, durch falsche Informationen aus dem Internet, die

Schnittstelle umgekehrt. Nach einem Öffnen des Steckers eines original Controllers bemerkte ich das Problem.

### Ich benutzte ein PS-Verlängerungskabel von EAXUS um den PS-Controller anzuschließen (ohne ihn unbrauchbar für die Playstation zu machen). Vom Verlängerungskabel benutzte ich die PS-Female Schnittstelle mit ca. 20 cm Kabel. Das andere Ende des Kabels habe ich auf

einen SUB-D gelötet.
Jetzt aber noch zu einem anderen Grund des Problems: Wie auf dem Bild zu sehen ist,

### verwendet der Hersteller des Verlängerungskabels nicht die gleiche Reihenfolge der Adernfarben. Zwar konnte ich mit dem Messgerät erkennen welche Ader zu welchem Pin

gehört, aber anhand der Farbe war es mir nicht möglich zu erkennen das ich die Schnittstelle falsch verwende.

### Danach kam ich zu folgendem Ergebnis:

### Bitte beachten, dass die Clock-

Ader eine schwarze Schirmung hat, nicht wie abgebildet eine weiße.

### Wenn ich es schwarz dargestellt hätte, hätte man nichts erkennen können. ;)

### 1. (Ausgang) DATA, serielle Datenübertragung - bei negativer Flanke von CLOCK sendet der Controller ein Bit über die DATA Leitung

- die Datenübertragung beginnt mit dem niederwertigsten Bit ( LSB-Verfahren ).

### 2. (Eingang) COMMAND, serielle Datenübertragung - bei negativer Flanke von CLOCK ließt der Controller das Bit auf der COMMAND Leitung 3. Nicht belegt 4. (Eingang) GND - Pin an Masse 5. (Eingang) VCC - Pin zur +5V Spannungsquelle

6. (Eingang) ATT - bevor der Controller Daten erhält, muss hier 0V (Masse) anliegen.

### 7. (Eingang) CLOCK - zur synchronisierten Übertragung 8. Nicht belegt 9. (Ausgang) ACK - sendet ein Signal, wenn ein Byte über COMMAND angekommen ist

Aryan Layes | www.Projekt07.dl.am | HBFI05a

## 2.3 Kommunikations-Protokoll des Playstation Controllers

### Bevor der Controller überhaupt weiß, dass er jetzt „dran“ ist und die COMMAND Leitung abhört, muss ATT auf Masse liegen (0V). Da der PS-Controller nicht gerade der schnellste

ist, sollte man hier ca. 50µs warten, bevor es mit der seriellen Übertragung losgeht.
Die serielle Übertragung besteht bei einem Analog Controller aus 9 Bytes, bei einem Digital

### Controller nur aus 5 Bytes. Eine Übertragung mit 9 Bytes bei einem Digital Controller

funktioniert dennoch, dazu aber später mehr.

### Die Übertragung erfolgt nach dem LSB-Verfahren!

In der folgenden Tabelle ist der Übertragungsablauf dargstellt. Dieses Beispiel bezieht sich auf die Kommunikation mit einem „Analog Red Mode Controller“.

### *Controller-Typ

Controller | Controller | empfangener Wert
| Standard Digital Controller | 0x41
| Analog Controller in Red Mode | 0x73
| Analog Controller in Green Mode | 0x53
| NegCon (Racing Controller) | 0x23
| PSX Maus | 0x12

### Quelle: http://www.technick.net/public/code/cp_dpage.php?aiocp_dp=pinconjoy_psx

Byte | COMMAND Hex Binär | DATA Hex Binär | empfangene Information
1 | 0x01 | 0000 0001 | - | - | -
2 | 0x42 | 0100 0010 | 0x73 | 0111 0011 | Controller-Typ*
3 | 0x00 | 0000 0000 | 0x5A | 0101 1010 | Status*
4 | 0x00 | 0000 0000 | 0xXX | xxxx xxxx | Zustände der linken Tasten*
5 | 0x00 | 0000 0000 | 0xXX | xxxx xxxx | Zustände der rechten Tasten*
6 | 0x00 | 0000 0000 | 0xXX | xxxx xxxx | Position des rechten Joysticks x-Achse*
7 | 0x00 | 0000 0000 | 0xXX | xxxx xxxx | Position des rechten Joysticks y-Achse*
8 | 0x00 | 0000 0000 | 0xXX | xxxx xxxx | Position des linken Joysticks x-Achse*
9 | 0x00 | 0000 0000 | 0xXX | xxxx xxxx | Position des linken Joysticks y-Achse*

Aryan Layes | www.Projekt07.dl.am | HBFI05a

### *Status

Wenn das empfangene Byte ungleich 01011010 ist, ist der Controller nicht bereit oder sogar

### defekt! Die Zustände der Tasten, die in der folgenden Übertragung empfangen werden, sind

wahrscheinlich unbrauchbar.

### Allgemeines zum Zustand der Tasten:

Wenn eine Taste gedrückt ist, sendet der Controller an der Stelle eine 0.

### Im englischen heißt das, dass die Tasten „active low“ sind !

### *linke Tasten Zu den linken Tasten gehören:

Die Zustände der gelb markierten Tasten sind bei einem Standart Digital Controller, der keine Joysticks hat, immer auf 1.

### *rechte Tasten Zu den rechten Tasten gehören:

### *Position des rechten/linken Joysticks [x-Achse]/[y-Achse]

Die Joysticks sind so hergestellt, dass sie auf der x-Achse und y-Achse jeweils 256 Zustände annehmen können. Diese Genauigkeit reicht völlig aus und braucht auch nur ein Byte für eine Achse.

### Wenn das Joystick ganz centriert ist (nicht bewegt) x-Achse = 1000 0000 b = 128 dez (genau die Hälfte der möglichen Zustände) y-Achse = 1000 0000 b = 128 dez (genau die Hälfte der möglichen Zustände)

### x-Achse < 1000 0000 b => Joystick ist nach links gedrückt x-Achse > 1000 0000 b => Joystick ist nach rechts gedrückt

### y-Achse < 1000 0000 b => Joystick ist nach oben gedrückt y-Achse > 1000 0000 b => Joystick ist nach unten gedrückt

Aryan Layes | www.Projekt07.dl.am | HBFI05a

Jetzt sollte jedem klar sein, was die empfangenen Daten bedeuten. Deshalb gehen wir jetzt zu der Übertragung selbst.

### Zur Übertragung brauchen wir die COMMAND, die DATA, die CLOCK und die ATT-

Leitung.

### 1. Ausgangssituation: Zustand vor der Übertragung: COMMAND = 0 CLOCK = 1 ATT = 1

### 2. Übertragungsvorbereitungen Die ATT-Leitung (hab ich vorhin schon erwähnt) muss auf 0 geschaltet werden und wegen

des langsamen Controllers sollte danach eine Wartezeit von ca. 50µs eingehalten werden.

### Nach den 50µs legen wir das erste Bit, das wir übertragen möchten, auf die COMMAND-

Leitung.

### 3. Übertragung Danach setzen wir CLOCK von 1 auf 0 um eine negative Flanke zu erzeugen. Jetzt braucht der Controller ca. 15µs um das Bit zu lesen und zu verarbeiten, also muss auch hier eine Wartezeit von 15µs eingehalten werden. CLOCK wird danach wieder auf 1 gesetzt und das

nächste Bit kommt auf die COMMAND-Leitung. Gehe zu 3. Übertragung.

### 4. Empfangen während der Übertragung

Ein bisschen „komplizierter“ wird es bei dem Übertragen und gleichzeitigen Empfangen.

### Das Bit, das übertragen werden soll, kommt auf die COMMAND-Leitung, CLOCK wird von 1 auf 0 gesetzt. Jetzt muss 15µs gewartet werden, danach wird überprüft ob auf der

DATA-Leitung eine 1 oder 0 liegt und der entsprechende Wert gespeichert.

### Hier ist das Zeit-Signal Diagramm der Übertragung der ersten beiden Bytes an einen Analog

Red Mode Controller dargestellt. Der vertikale Strich trennt die beiden Bytes.

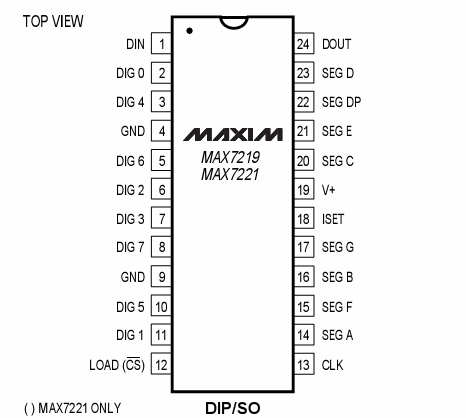
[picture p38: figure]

Aryan Layes | www.Projekt07.dl.am | HBFI05a

## 2.4 MAX7219 I/O

### Mit Hilfe der schematischen Abbildung des MAX 7219 LED Display Treibers werde

ich dessen einzelnen Ein- und Ausgänge beschreiben.

### Spannungs- und Stromversorgung 19. V+ (+5V) Spannungsquelle 4 & 9. GND

5. ISET Helligkeitsregelung der LED Anzeige über extern geschalteter Widerstand.

### I/O Kommunikation/Steuerung des MAX-IC’s 1. (Eingang) DIN, serielle Datenübertragung

- die Datenübertragung beginnt mit dem letzten Bit 15 ( MSB-Verfahren ).
- bei positiver Flanke von CLK übernimmt der MAXIM das anstehende Bit an DIN.

### 12. (Eingang) LOAD - die Übertragung beginnt mit dem Schalten von LOAD auf 0V (Masse). Die zwei Bytes werden transferiert und danach wird LOAD wieder auf 1(+5V)

geschaltet.

13. (Eingang) CLK - zur synchronisierten Übertragung der Bits über DIN LED Steuerung 6. (Ausgang) DIG 0 bis DIG 7 – Jede LED wird über dazugehörigen Digitausgang angesteuert, dies geschieht über die Kathoden der LEDs 7. (Ausgang) SEG DP - G – Die einzelnen Segmente der Digits werden mit den gleichen Segmenten der anderen Digits verbunden. Zum Beispiel: Anode der SEG DP LED im Digit 0 ist verbunden mit der Anode der SEG DP LED im Digit

1.


Aryan Layes | www.Projekt07.dl.am | HBFI05a

## 2.5 MAX7219 Steuerung

Die Steuerung des MAX7219 erfolgt über zwei Byte lange Befehle.

Das zweite Byte (links) gibt an auf welches Register des MAX7219 zugegriffen wird. Mit dem ersten Byte (rechts) werden die Werte in dem Register festgelegt.

### Die folgende Tabelle aus dem Datenblatt des MAX7219 zeigt welche Register zur

Verfügung stehen.

### Digit 0-7: speichert die Zustände der Segmente

### Decode Mode:

Der MAX7219 wurde so entwickelt,

### dass er neben der ganz normalen Ausgabe der Digits einen integrierten BCD-Decoder bereitstellt. Auf diesen werde ich in meiner Dokumentation

aber nicht eingehen.

### Intensity: Auch hier gibt es eine spezielle Funktion des Display Treibers. Die Helligkeitssteuerung kann über den ISET-Eingang, oder durch dieses Register erfolgen. Da ich in meinem Projekt keine Helligkeitssteuerung verwende und das Datenblatt die

Informationen zu diesem Feature beinhaltet, gehe ich nicht näher darauf ein.

### Scan Limit: Über dieses Register lässt sich einstellen wie viele Digits genutzt werden. Nicht benutzte Digits sollten nicht aktiviert werden, da diese die Helligkeit der Anzeige

„dimmen“ würden.

### Shutdown:

Mit diesem Register wird die Anzeige ein- und ausgeschaltet.

### Shutdown: Mit diesem Register kann die Anzeige geprüft werden. Im Testmodus sollten alle

LEDs an sein.

Aryan Layes | www.Projekt07.dl.am | HBFI05a

## 3.0 Neue Programmiermethoden

### Im Laufe der Programmierung vergrößerte sich mein Programmcode. Deshalb habe ich gegen Ende der Projektfertigstellung mir überlegt, wie ich einige Funktionen

verändern kann um den Programmcode zu minimieren.

### Ich bin zu dem Entschluss gekommen, das die Kommunikation mit dem PS-Controller

und dem MAX7219 über Tabelle eine starke Optimierung des Codes erreichen kann.

### Problem: Wie kann ich aus einer Tabelle einen nicht konstanten Wert laden?

### Lösung:

Erstellung „dynamischer Tabellen“ durch indirekte Adressierung.

### Die indirekte Adressierung wird in den Flussdiagrammen der Unterprogramme

UP_PSC_send_tabelle und UP_MAX_send_tabelle genauestens erklärt.

## 3.1 Quellcode

; *********************************************************** ; * Projekt07_4_1.asm - Playstation Controller an PIC16F84A *
; *********************************************************** ;
; | Aryan Layes | HBFI05a | 04/2007
;
; | Der PIC soll mit einem PS-Controller kommunizieren
; | und erkennen welche Tasten auf dem Controller gedrückt wurden.
;
; | Wenn er weiß. was gedrückt wurde, schaltet er die zu den
; | entsprechenden Tasten gehörenden LED's ein bzw. aus.
;
; Anzeige -> MAX7219 LED Display Treiber aus dem Hause MAXIM
;
; ############################################################################# ;
; | D: Digitaler Controller (keine Joysticks)
; | A: Analoger Controller (2 Joysticks)
;
;RxByte Type | Taste | Hex | Binär
;-------------------------------------------
;1 | D/A | Left | 0xFE | 11111110
;1 | D/A | Down 0xFD 11111101
;1 | D/A | Right 0xFB 11111011
;1 | D/A | Up | 0xF7 | 11110111
;1 | D/A | Start | 0xEF | 11101111
;1 | A | Joy-R 0xDF 11011111 | ---- Nur Analoger Controller
;1 | A | Joy-L 0xBF 10111111 | ---- Nur Analoger Controller
;1 | D/A | Select 0x7F | 01111111
;-------------------------------------------
;2 | D/A | [] | 0xFE | 11111110
;2 | D/A | X | 0xFD 11111101
;2 | D/A | O | 0xFB 11111011
;2 | D/A | /_\ | 0xF7 | 11110111
;2 | D/A | R1 | 0xEF | 11101111
;2 | D/A | L1 | 0xDF 11011111
;2 | D/A | R2 | 0xBF 10111111
;2 | D/A | L2 | 0x7F | 01111111
;-------------------------------------------
; Mehrere Buttons werden UND verknüpft... ;-------------------------------------------
; | A | Joy-R-X
; | A | Joy-R-X
; | A | Joy-R-X
; | A | Joy-R-X
; | A | Joy-R-X
; | A | Joy-R-X
; | A | Joy-R-X
; | A | Joy-R-X
; | -----------------------------------
; | A | Joy-R-Y
; | A | Joy-R-Y
; | A | Joy-R-Y
; | A | Joy-R-Y
; | A | Joy-R-Y
; | A | Joy-R-Y
; | A | Joy-R-Y
; | A | Joy-R-Y
; | -----------------------------------

; | A | Joy-L-X
; | A | Joy-L-X
; | A | Joy-L-X
; | A | Joy-L-X
; | A | Joy-L-X
; | A | Joy-L-X
; | A | Joy-L-X
; | A | Joy-L-X
; | -----------------------------------
; | A | Joy-L-Y
; | A | Joy-L-Y
; | A | Joy-L-Y
; | A | Joy-L-Y
; | A | Joy-L-Y
; | A | Joy-L-Y
; | A | Joy-L-Y
; | A | Joy-L-Y
; | -----------------------------------
;
; **************************************************************
; * | Changelog beta_4_1 | *
; **************************************************************
; | Überprüfung ob Controller bereit
; | wenn nicht bereit-> MAX Digits löschen
; | und dann warten bis Controller wieder bereit
; **************************************************************
; * | Changelog beta_4_0 | *
; **************************************************************
; | Register Invertierung
; | gLEFT und gRIGHT, sodass nur noch die
; | LED's der Taste an sind, die auch
; | gedrückt sind.
;
;
;*************************************************************************** ;* Bestimmung des Prozessortyps für den Assembler und das Programmiergerät * ;***************************************************************************

LIST p=16F84A

;******************************************************************* ;* Includedatei für den 16F84A einbinden (vordef. Reg. und Konst.) * ;*******************************************************************

#include <p16f84A.INC>

; Diese Datei enthält Vordefinitionen für wichtige Register und Konstanten.
; (Z.B. gibt es die Konstante PORTB mit der sich ohne Angabe der
; absoluten Adresse H'0006' der Port B des Prozessors ansprechen lässt)

;********************************************************* ;* Konfigurationseinstellungen für IC-Prog vordefinieren * ;*********************************************************

__CONFIG _PWRTE_ON & _CP_OFF & _HS_OSC & _WDT_OFF

; Hier werden verschiedene Prozessoreigenschaften festgelegt:
; _PWRTE_ON schaltet den Power Up Timer ein, d.h. der Prozessor wartet nach
; | dem Einschalten ca. 70ms mit dem Programmstart, um sicher zu sein,
; | dass alle angeschlossene Peripherie bereit ist.

; _CP_OFF schaltet die Code-Protection des Prozesors aus. Damit ist das im Prozessor
; befindliche Programm jederzeit auslesbar und überschreibbar.
; _HS_OSC spezifiziert einen Quarzoszillator (Highspeed) als Zeitbasis für den Prozessor. ; _WDT_OFF schaltet den Watchdog-Timer des Prozesors aus.

;***********************************
;* Register / Variablen festlegen *
;***********************************
; hier werden Adressen von Registern / Variablen festgelegt. Diese werden beginnend ; mit der Adresse H'20' aufsteigend vergeben.

CBLOCK H'20'

;Register des PS2 Controller

sPSC | ;Übertragungsregiser (dynamische Tabelle)
sIDLE | ;IDLE-Register (= 0)
sSTART | ;START-Befehl (00000001)
gSTART | ;um später die PS2 Kommunikation per
;dynamische Tabelle ab zu arbeiten
sTYPE | ;GET TYPE-Befehl (01000010)
gTYPE | ;Empfangene Daten nach dem GET TYPE Befehl
gSTATUS | ;Status des Controllers (0x5A wenn bereit)
rSTATUS | ;Register um gSTATUS mit 0x5A zu vergleichen
gLEFT | ;Status der Buttons:
;<- | \/ | -> | /\ | Start | JL | JR | Select
gRIGHT | ;Status der Buttons:
;[] | X | O | /_\ | R1 | L1 | R2 | L2
gRJoyX | ;X Position des rechten Joysticks
gRJoyY | ;Y Position des rechten Joysticks
gLJoyX | ;X Position des linken Joysticks
gLJoyY | ;X Position des linken Joysticks
;14 Register

;Warteschlangen

;wait_20us | ;Wartezeit nach dem a_ATT auf 0 geht
wait_50us | ;Wartezeit nach dem a_ATT auf 0 geht | ;NEW
;wait_5us | ;Wartezeit zwischen CLOCK LOW und HIGH
wait_25us | ;Wartezeit zwischen CLOCK LOW und HIGH | ;NEW
;2 Register

;Register des MAX-7219

zaehler_bit | ;Zaehler der einzelnen Übertragenene Bits
zaehler_tab | ;Zaehler um in der MAX-Tabelle zu springen
sMAX | ;Register das zur Kommunikation zwischen PIC
;und MAX-7219 dient
;3 Register

;zur Initialisierung:

;MAX Digit Kodierungs
;kMODUS_adr ;Modusbefehlsadresse
;m_MODUS | ;MAX Digit Kodierungsmodus
m_D_MODUS_adr | ; 0x09 Digit Kodierungsmodus Adresse
m_D_MODUS ; 0x00 MAX Digit Kodierungsmodus | ->keine Kodierung<-

;MAX Digit Helligkeit
m_HELLIGKEIT_adr | ; 0x0A MAX Helligkeitssteuerung Adresse
m_HELLIGKEIT | ; 0x15 MAX Helligkeitssteuerung | ->Digit 31 / 32 (max
ON)<-

;MAX Digit Anzahl
m_DIGITS_adr ; 0x0B Digitsanzahl Adresse
m_DIGITS | ; 0x01 Anzahl der aktivierten Digits | ->Digit 0 und 1<-

;MAX Shutdown
;kSTART_adr ; 0x0C Startbefehlsadresse
;m_START | ; 0x01 MAX Shutdownbefehl | ->Normal
Operation<-
m_SHUTDOWN_adr | ; 0x0C SHUTDOWN Adresse
m_SHUTDOWN ; 0x01 MAX Shutdownbefehl | ->Normal Operation<-

;MAX Test
m_TEST_adr | ; 0x0F Testbefehlsadresse
m_TEST | ; 0x00 MAX Testmodus | ->KEIN
TESTMODUS<-
;10 Register

;zur Digitauswahl

m_TYPE_adr ; Type - Digit-Adresse m_STATUS_adr ; Status - Digit-Adresse

m_LEFT_adr ; LINKS - Digit-Adresse
m_RIGHT_adr ; RECHTS - Digit-Adresse

m_RJoyX_adr ; Joystick rechts x-Achse - Digit-Adresse m_RJoyY_adr ; Joystick rechts y-Achse - Digit-Adresse

m_LJoyX_adr ; Joystick links x-Achse - Digit-Adresse m_LJoyY_adr ; Joystick links y-Achse - Digit-Adresse

m_display_r
m_display_c
m_display_l
;8 Register

;Register um zu Überprüfen ob Controller bereit zaehler

;Register für die debugging Funktionen.....

wait_05s
wait_05s_1
wait_05s_2

;3 Register

;40 Register insgesammt -> Bank 0 reicht dafuer aus
ENDC

;***************************************************************
; | * Konstanten festlegen *
;***************************************************************

;*****************************************
; * Konstanten des MAX-7219 * ;*****************************************

; *********************************************************************** ; * Definition von einzelnen Bits in einem Register / in einer Variable *
; ***********************************************************************

;##################### Ports zum Controller ################### ;##################### ___________________________ ###################
#DEFINE | e_DATA | PORTA, 0 | ; Data | Eingang

#DEFINE | a_COMMAND PORTA, 1 | ; Command | Ausgang

#DEFINE | a_CLOCK | PORTA, 2 | ; Takt | Ausgang

#DEFINE | a_ATT | PORTA, 3 | ; ATT | Ausgang

;#DEFINE | a_ACK | PORTA, 4 | ; ACK Eingang NICHT BENUTZT

;###################### Ports zur Anzeige ##################### ;###################### ________________________ #####################
;#DEFINE | a1 | PORTB, 0 | ; DEBBUGING Ausgang
;#DEFINE | b1 | PORTB, 1 | ; | Ausgang
;#DEFINE | c1 | PORTB, 2 | ; | Ausgang
;#DEFINE | d1 | PORTB, 3 | ; | Ausgang
;###############################
;#DEFINE | a2 | PORTB, 4 | ; | Ausgang
;#DEFINE | b2 | PORTB, 5 | ; | Ausgang
;#DEFINE | c2 | PORTB, 6 | ; | Ausgang
;#DEFINE | d2 | PORTB, 7 | ; | Ausgang
;###############################
#DEFINE | a_MAX_DATA PORTB, 0 | ; MAX-7219-DATA | Ausgang

#DEFINE | a_MAX_LOAD PORTB, 1 | ; MAX-7219-LOAD | Ausgang

#DEFINE | a_MAX_CLOCK | PORTB, 2 | ; MAX-7219-CLOCK | Ausgang

;#####################################################################
#DEFINE | bank1 | STATUS, RP0

;#####################################################################

;*****************
;* Programmstart *
;*****************
ORG | H'00' | ; Das Programm wird ab Speicherstelle 0 in den
; Speicher geschrieben
GOTO init ; Springe zur Grundinitialisierung der Ports A und B

;*******************
;* Initialisierung *
;*******************
init | BSF | bank1 ; wechsle zu Registerbank 1 (spezielle Register)
MOVLW | B'00000001'
MOVWF | TRISA ; RA0 Eingang (RA1 bis RA7 sind Ausgänge)
MOVLW | B'00000000'

MOVWF TRISB ; RB0 bis RB7 sind Ausgänge

; Die Register TRISA und TRISB legen fest, welche Bits in den jeweiligen Ports ; Ein- bzw. Ausgänge sind. Eine '1' an der entsprechenden Stelle setzt das Bit
; des Ports als Eingang eine '0' setzt das Bit als Ausgang.

BCF bank1 ; wechsle zu Registerbank 0
; (normaler Speicherbereich)

CLRF PORTA ; Port A löschen
CLRF PORTB ; Port B löschen

;PS2 - Übertragungsregister
;
CLRF sIDLE
MOVLW | B'00000001'
MOVWF | sSTART | ;START-Befehl (00000001) = H'01'
MOVLW | B'01000010'
MOVWF | sTYPE | ;GET-TYPE-Befehl (01000010) = H'42'

;PS2 - Vergleichsregister
;
MOVLW | B'01011010' | ; = 0x5A = Status des Controller wenn bereit
MOVWF | rSTATUS | ;Register wird zum Vergleichen benutzt
;wenn Controller nicht bereit ist soll von ;er zurück zu main springen und die ;Anzeige löschen

;MAX - Register zur Initialisierung
;
;Ich haette auch alle (hab ich auch in einer früheren Programmversion) ;Initialisierungs Adressen/Befehle in Konstanten schreiben können. Da ich aber ;bei der Programmminimierung mir eine Senderoutine überlegt habe, die mit einer ;dynamischen Tabelle die komplette Übertragung (Initialisierung + Anzeige) ab ;arbeitet verwende ich jetzt Register.
MOVLW | B'00001011' | ; 0x0B Digitsanzahl Adresse
MOVWF | m_DIGITS_adr
MOVLW | B'00000100' | ; 0x01 Anzahl der aktivierten Digits
MOVWF | m_DIGITS | ; ->Digit 0 bis 4<-
MOVLW | B'00001100' | ; 0x0C SHUTDOWN Adresse
MOVWF | m_SHUTDOWN_adr
MOVLW | B'00000001' | ; 0x01 MAX Shutdownbefehl
MOVWF | m_SHUTDOWN ; ->Normal Operation<-
MOVLW | B'00001111' | ; 0x0F Testbefehlsadresse
MOVWF | m_TEST_adr
MOVLW | B'00000000' | ; 0x00 MAX Testmodus
MOVWF | m_TEST | ; ->kein Testmodus<-
MOVLW | B'00001001' | ; 0x09 Digit Kodierungsmodus Adresse
MOVWF | m_D_MODUS_adr
MOVLW | B'00000000' | ; 0x00 MAX Digit Kodierungsmodus
MOVWF | m_D_MODUS ;->keine Kodierung<-
MOVLW | B'00001010' | ; 0x0A MAX Helligkeitssteuerung Adresse
MOVWF | m_HELLIGKEIT_adr
MOVLW | B'00001111' | ; 0x15 MAX Helligkeitssteuerung

MOVWF | m_HELLIGKEIT | ; ->Digit 31 / 32 (max ON)<-

;MAX - Register zur Digitzuweisung
;
;Könnte auch mit einem Zaehler gemacht werden, aber ich möchte auswählen ;wo welches Register angezeigt werden soll und auserdem ist es jetzt möglich ;die Initialisierung und die Anzeige in einem Unterprogramm ab zu arbeiten
MOVLW | B'00000001' | ; LINKS - Digit-Adresse
MOVWF | m_LEFT_adr | ; -> Digit 0
MOVLW | B'00000010' | ; RECHTS - Digit-Adresse
MOVWF | m_RIGHT_adr ; -> Digit 1
MOVLW | B'00000011' | ; Joystick rechts, x-Achse - Digit-Adresse
MOVWF | m_RJoyX_adr ; -> Digit 2
MOVLW | B'00000100' | ; Joystick rechts, y-Achse - Digit-Adresse
MOVWF | m_RJoyY_adr ; -> Digit 3
MOVLW | B'00000101' | ; Joystick links, x-Achse - Digit-Adresse
MOVWF | m_LJoyX_adr ; -> Digit 4
MOVLW | B'00000110' | ; Joystick links, y-Achse - Digit-Adresse
MOVWF | m_LJoyY_adr ; -> Digit 5

;MAX - Starteinstellungen
;
BSF | a_MAX_LOAD ; MAX-Baustein soll am Anfang nicht im ...
BSF | a_MAX_CLOCK | ; ...Übertragungsmodus sein
;*****************
;* Hauptprogramm *
;*****************

main

CLRF m_display_r | ;Display Bits löschen
CLRF m_display_c | ;Display Bits löschen
CLRF m_display_l | ;Display Bits löschen
BSF | a_ATT | ; ATT auf HIGH, Controller wird abgewählt
; (ignoriert alle Daten)
CALL UP_wait_25us
BSF | a_CLOCK | ; Clock HIGH
BSF | a_COMMAND ; Command HIGH
BCF | a_ATT | ; ATT auf LOW das der Controller
; die Daten annimmt

CALL UP_wait_50us ; Warteschlange bis Controller bereit ist

;#########
; | BSF | a1;;;;;;;;; ;-----DEBUGGING
CALL UP_PSC_send_tabelle
COMF gLEFT,F | ;Speicherzellen werden invertiert ( 1 zu 0
COMF gRIGHT,F | ;und 0 zu 1). Weil wenn eine Taste gedrückt
;ist dann liegt ein 0 Signal am PIC an
MOVF rSTATUS,W | ;Controller Status auf Zustand "bereit"
SUBWF gSTATUS | ;prüfen...

BTFSS STATUS,Z | ;Wenn breit, Zerobit = 1
GOTO nicht_bereit | ;<- Controller nicht bereit...
;<- Controller bereit...
MOVLW | D'1'
MOVWF | zaehler | ;falls der Controller wieder
;keine Verbindung hat, das die LEDs ;auf 0 gesetzt werden!

;#########
| ;BCF | d2 | ;------DEBUGGING
CALL UP_Display_r | ;rechte Display LED auswählen
CALL UP_Display_l | ;linke Display LED auswählen
| ;BSF | d2 | ;------DEBUGGING
;#########

;#########
max
; | BSF | d2 | ;------DEBUGGING
CALL UP_MAX_send_tabelle ;Ausgabe
; | BCF | d2 | ;------DEBUGGING
;#########
GOTO main | ;Springe wieder an den Anfang zurück

nicht_bereit
MOVF zaehler,F
BTFSC STATUS,Z
GOTO main
DECF zaehler
GOTO max

;******************
;* Unterprogramme *
;******************
;############################################################################### ;############################################################################### UP_PSC_send_tabelle
MOVLW | D'0'
MOVWF | zaehler_tab
PSC_st1 MOVLW | D'8'
MOVWF | zaehler_bit
BCF | STATUS, IRP | ; Bank 0 oder 1 (alle Register aus der
; Tabelle sind in Bank 0)

MOVF zaehler_tab,W ;wird mit dem PCL addiert

CALL tab_PSC | ;Öffnet die "dynamische Tabelle"
;Im Workregister steht jetzt die Adresse ;des Registers dessen Inhalt ;Übertragen werden soll
MOVWF | FSR | ;der Zeiger zeigt jetzt auf das Register
;dessen Inhalt Übertragen werden soll

MOVF INDF,W | ;mit dem virtuellen Register INDF kann der
;Inhalt des Registers ausgegeben werden, ;auf das der Zeiger FSR zeigt
MOVWF | sPSC | ;Inhalt wird in sende Register kopiert,
;da ein weiteres Register aus der Tabelle ;benötigt wird um die empfangenen Bits zu ;speichern

INCF zaehler_tab ;nächste Tabellenreihe

MOVF zaehler_tab,W ;wird mit dem PCL addiert
CALL tab_PSC | ;Öffnet die "dynamische Tabelle"
;Im Workregister steht jetzt die Adresse ;des Registers in das geschrieben wird
MOVWF | FSR | ;der Zeiger zeigt jetzt auf das Register
;in das die empfangenen Bits gespeichert ;werden
;-
;mit dem virtuellen Register INDF kann der ;Inhalt des Registers geändert werden, ;auf das der Zeiger FSR zeigt
PSC_1 RRF | sPSC | ;verschiebe sende Register nach rechts...
BTFSS STATUS,C | ;prüfe Wertigkeit des rausgeworfenen Bits
GOTO PSC_sende_0 | ;(STATUS,C=0)-> Übertrage 0 an Controller...
GOTO PSC_sende_1 | ;(STATUS,C=1)-> ansonsten Übertrage '1'

PSC_2 DECF zaehler_bit
MOVF zaehler_bit,F | ; Zähler ...
BTFSS STATUS,Z | ; ... auf 0 prüfen,
GOTO PSC_1 | ; <-- Zähler != 0 --> nächstes Bit übertrag.
; <-- Zähler == 0

INCF zaehler_tab
MOVLW | D'18' | ;PS2-Analog-Mode Controller
SUBWF zaehler_tab,W
BTFSS STATUS,Z
GOTO PSC_st1 | ;zaehler_tab < 18
RETURN | ;zaehler_tab = 18
;###########################################################
PSC_sende_0
BCF | a_COMMAND ;auf 0 setzten
BCF | a_CLOCK | ;negative Flanke (Controller ließt COMMAND)
CALL UP_wait_25us ;aber erst nach 25µs !!!
BTFSC e_DATA | ;e_DATA prüfen
GOTO INDF_0_write_1 ;empfangenes Bit in Carry-Flag setzen
GOTO INDF_0_write_0 ;empfangenes Bit in Carry-Flag setzen PSC_sende_0_next
RRF | INDF | ;empfangenes Bit in Register hinzufügen
BSF | a_CLOCK
CALL UP_wait_25us
GOTO PSC_2
;###################################### INDF_0_write_1
BSF STATUS,C
GOTO PSC_sende_0_next
INDF_0_write_0 | ;zur Übersicht, hier geschrieben!!!

BCF STATUS,C
GOTO PSC_sende_0_next
;###########################################################
PSC_sende_1
BSF | a_COMMAND ;auf 1 setzten
BCF | a_CLOCK | ;negative Flanke (Controller ließt COMMAND)
CALL UP_wait_25us ;aber erst nach 4µs !!!
BTFSC e_DATA | ;e_DATA prüfen
GOTO INDF_1_write_1 ;empfangenes Bit in Carry-Flag setzen
GOTO INDF_1_write_0 ;empfangenes Bit in Carry-Flag setzen PSC_sende_1_next
RRF | gTYPE | ;empfangenes Bit in Register hinzufügen
BSF | a_CLOCK
CALL UP_wait_25us
GOTO PSC_2
;###################################### INDF_1_write_1
BSF STATUS,C
GOTO PSC_sende_1_next
INDF_1_write_0 | | ;zur Übersicht, hier geschrieben!!!
BCF | STATUS,C
GOTO PSC_sende_1_next
;###############################################################################
UP_Display_r | | ;Positionsberechnung Joystick rechts
MOVLW | D'85'
SUBWF gRJoyX,W
BTFSC STATUS,C
GOTO x_groesser_85

x_kleiner_gleich_85
MOVLW D'85'
SUBWF gRJoyY,W
BTFSC STATUS,C
GOTO y_groesser_85
y_kleiner_gleich_85
BSF m_display_r,6
RETURN

y_groesser_85
MOVLW D'170'
SUBWF gRJoyY,W
BTFSC STATUS,C
GOTO y_groesser_170
y_kleiner_gleich_170
BSF m_display_r,7
RETURN

y_groesser_170
BSF m_display_r,0
RETURN
;#################################### ;#################################### x_groesser_85
MOVLW D'170'
SUBWF gRJoyX,W
BTFSC STATUS,C
GOTO x_groesser_170
x_kleiner_gleich_170
MOVLW D'85'

SUBWF gRJoyY,W
BTFSC STATUS,C
GOTO y_2_groesser_85
y_2_kleiner_gleich_85
BSF m_display_r,5
RETURN

y_2_groesser_85
MOVLW D'170'
SUBWF gRJoyY,W
BTFSC STATUS,C
GOTO y_2_groesser_170
y_2_kleiner_gleich_170
BSF m_display_c,0
RETURN

y_2_groesser_170
BSF m_display_r,1
RETURN

;#################################### ;#################################### x_groesser_170
MOVLW D'85'
SUBWF gRJoyY,W
BTFSC STATUS,C
GOTO y_3_groesser_85
y_3_kleiner_gleich_85
BSF m_display_r,4
RETURN

y_3_groesser_85
MOVLW D'170'
SUBWF gRJoyY,W
BTFSC STATUS,C
GOTO y_3_groesser_170
y_3_kleiner_gleich_170
BSF m_display_r,3
RETURN

y_3_groesser_170
BSF m_display_r,2
RETURN
;###############################################################################
UP_Display_l | | ;Positionsberechnung Joystick links
MOVLW | D'85' | ;links und rechts kann auch wieder mit
SUBWF gLJoyX,W | ;Tabelle minimiert weden!
BTFSC STATUS,C
GOTO _x_groesser_85

_x_kleiner_gleich_85
MOVLW D'85'
SUBWF gLJoyY,W
BTFSC STATUS,C
GOTO _y_groesser_85
_y_kleiner_gleich_85
BSF m_display_l,6
RETURN

_y_groesser_85
MOVLW D'170'
SUBWF gLJoyY,W
BTFSC STATUS,C
GOTO _y_groesser_170
_y_kleiner_gleich_170
BSF m_display_l,7
RETURN

_y_groesser_170
BSF m_display_l,0
RETURN
;#################################### ;#################################### _x_groesser_85
MOVLW D'170'
SUBWF gLJoyX,W
BTFSC STATUS,C
GOTO _x_groesser_170
_x_kleiner_gleich_170
MOVLW D'85'
SUBWF gLJoyY,W
BTFSC STATUS,C
GOTO _y_2_groesser_85
_y_2_kleiner_gleich_85
BSF m_display_l,5
RETURN

_y_2_groesser_85
MOVLW D'170'
SUBWF gLJoyY,W
BTFSC STATUS,C
GOTO _y_2_groesser_170
_y_2_kleiner_gleich_170
BSF m_display_c,1
RETURN

_y_2_groesser_170
BSF m_display_l,1
RETURN

;#################################### ;#################################### _x_groesser_170
MOVLW D'85'
SUBWF gLJoyY,W
BTFSC STATUS,C
GOTO _y_3_groesser_85
_y_3_kleiner_gleich_85
BSF m_display_l,4
RETURN

_y_3_groesser_85
MOVLW D'170'
SUBWF gLJoyY,W
BTFSC STATUS,C

GOTO _y_3_groesser_170
_y_3_kleiner_gleich_170
BSF m_display_l,3
RETURN

_y_3_groesser_170
BSF m_display_l,2
RETURN
;############################################################################### UP_MAX_send_tabelle
MOVLW | D'0'
MOVWF | zaehler_tab | ;Wenn zaehler_tab ungerade, 2.Byte gesendet
;-> LOAD auf 1
MAX_st1 | MOVLW | D'8'
MOVWF | zaehler_bit
BCF | STATUS, IRP | ; Bank 0 oder 1

MOVF zaehler_tab,W ;wird mit dem PCL addiert

CALL tab_MAX | ;Öffnet die "dynamische Tabelle"
;Im Workregister steht jetzt die Adresse ;des Registers dessen Inhalt ;Übertragen werden soll
MOVWF | FSR | ;der Zeiger zeigt jetzt auf das Register
;dessen Inhalt Übertragen werden soll
MOVFW | INDF | ;mit dem virtuellen Register INDF kann der
;Inhalt des Registers ausgegeben werden, ;auf das der Zeiger FSR zeigt
;MOVWF | PORTB | ; #############DEBUGGING#############
;CALL UP_wait_05s | ; #############DEBUGGING#############
MOVWF | sMAX
BCF | a_MAX_LOAD ;Vor der Übertragung von 2 Bytes auf LOW
MAX_st2 | RLF | sMAX | ;MSB zuerst...
BTFSC STATUS,C
GOTO MAX_send_tabelle_1 ;MAX-Datenleitung auf HIGH (Übertrage 1)
BCF | a_MAX_DATA ;MAX-Datenleitung auf LOW | (Übertrage 0)
MAX_st3 | BCF | a_MAX_CLOCK | ;
;CALL UP_wait_05s | ; #############DEBUGGING#############
BSF | a_MAX_CLOCK | ;Positive Flanke erzeugen
BCF | a_MAX_CLOCK

DECF zaehler_bit
MOVF zaehler_bit,F | ; Zähler ...
BTFSS STATUS,Z | ; ... auf 0 prüfen,
GOTO MAX_st2 | ; <-- Zähler != 0 --> nächstes Bit übertrag.
; <-- Zähler == 0
BTFSC zaehler_tab,0 | ; nach jedem 2. Byte LOAD auf 1
BSF | a_MAX_LOAD ; <-- Zähler_tab == ungerade -> 2.Byte
; <-- Zähler_tab == gerade -> 1.Byte INCF zaehler_tab
MOVLW | D'20' | ;Platine, mit Joystickberechnung 20Bytes

SUBWF zaehler_tab,W
BTFSS STATUS,Z
GOTO MAX_st1 | ;zaehler_tab < 22
RETURN | ;zaehler_tab = 22

MAX_send_tabelle_1
| BSF | a_MAX_DATA
GOTO MAX_st3

;############################################################################### ;########################### Warteschleifen ########################### ;###############################################################################

;############################***********************############################ ;########################## ATTENTION Warteschleife ########################## ;UP_wait_20us
; | | ;100 cycles
; | movlw 0x21
; | movwf wait_20us
;loop20us_0
; | decfsz wait_20us, f
; | goto | loop20us_0
;RETURN
;########################## ATTENTION Warteschleife 2 ######################### UP_wait_50us
| | ;250 cycles
movlw 0x53
movwf wait_50us
loop50us_0
decfsz wait_50us, f
| goto | loop50us_0
RETURN
;########################**********************************##################### ;###################### CLOCK LOW - CLOCK HIGH Warteschleife ###################
;UP_wait_5us | ;UP_wait_5us
; | | ;25 cycles
; | movlw 0x08
; | movwf wait_5us
;loop5us_0
; | decfsz wait_5us, f
; | goto | loop5us_0
;RETURN
;##################### CLOCK LOW - CLOCK HIGH Warteschleife 2 ##################
UP_wait_25us | ;UP_wait_5us
| | ;124 cycles
movlw 0x29
movwf wait_25us
loop25us_0
decfsz wait_25us, f
| goto | loop25us_0
| | ;1 cycle
| nop
RETURN
;############################***********************############################ ;########################### DEBUGGING Warteschleife ########################### ;UP_wait_05s
; | | ;2499999 cycles
; | movlw 0x16
; | movwf wait_05s
; | movlw 0x74
; | movwf wait_05s_1

; | movlw 0x06
; | movwf wait_05s_2
;loop05s_0
; | decfsz wait_05s, f
; | goto | $+2
; | decfsz wait_05s_1, f
; | goto | $+2
; | decfsz wait_05s_2, f
; | goto | loop05s_0
;
; | ;1 cycle
; | nop
;RETURN
;###############################################################################
;########################### | Tabellen | ############################
;###############################################################################

;############################***********************############################
;########################### | PSC-Tabelle | ###########################
tab_PSC | ;Tabellenlänge: 18; -> zaehler_tab max. 18!
BCF | PCLATH,0 | ;PCLATH auf ...
BSF | PCLATH,1 | ;... 0x2 stellen
ADDLW | 0x50
MOVWF | PCL | ;PCL ist jetzt 0x250 + zaehler_tab
ORG | 0x250 | ; Tabelle in Speicherblock 2
RETLW sSTART | ; Playstation Controller - Startbefehl
RETLW gSTART | ; empfange... irgentwas
RETLW sTYPE | ; Playstation Controller - Typebefehl
RETLW gTYPE | ; empfange Type des Controllers
RETLW sIDLE | ; übertrage 0 Signal
RETLW gSTATUS | ; empfange Status des Controllers
RETLW sIDLE | ; übertrage 0 Signal
RETLW gLEFT | ; empfange Status der Tasten LINKS
RETLW sIDLE | ; übertrage 0 Signal
RETLW gRIGHT | ; empfange Status der Tasten RECHTS
RETLW sIDLE | ; übertrage 0 Signal
RETLW gRJoyX | ; empfange : Joystick rechts, x-Achse
RETLW sIDLE | ; übertrage 0 Signal
RETLW gRJoyY | ; empfange : Joystick rechts, y-Achse
RETLW sIDLE | ; übertrage 0 Signal
RETLW gLJoyX | ; empfange : Joystick links, x-Achse
RETLW sIDLE | ; übertrage 0 Signal
RETLW gLJoyY | ; empfange : Joystick links, y-Achse

;############################***********************############################
;########################### | MAX-Tabelle | ###########################
tab_MAX | ;Tabellenlänge: 22; -> zaehler_tab max. 22!
BSF | PCLATH,0 | ;PCLATH auf ...

BSF | PCLATH,1 | ;... 0x3 stellen
MOVWF | PCL | ;PCL ist jetzt 0x300 + zaehler_tab
ORG | 0x300 | ; Tabelle in Speicherblock 3

RETLW m_DIGITS_adr ; Anzahl der genutzten Digits
RETLW m_DIGITS | ;
RETLW m_SHUTDOWN_adr | ; Normalmodus oder Ausgeschaltet
RETLW m_SHUTDOWN ;
RETLW m_TEST_adr | ; Normalmodus oder Displaytest
RETLW m_TEST | ;
RETLW m_D_MODUS_adr | ; Dekodierungsmodus
RETLW m_D_MODUS ;
RETLW m_HELLIGKEIT_adr | ; Helligkeitssteuerung der LED's
RETLW m_HELLIGKEIT | ;
RETLW m_LEFT_adr | ; Tasten LINKS - Digit-Adresse
RETLW gLEFT | ; Tasten LINKS

RETLW m_RIGHT_adr ; Tasten RECHTS - Digit-Adresse
RETLW gRIGHT | ; Tasten RECHTS

RETLW m_RJoyX_adr ; Joystick rechts, x-Achse - Digit-Adresse RETLW m_display_r ; Joystick Positionsdisplay, rechts

RETLW m_RJoyY_adr ; Joystick rechts, y-Achse - Digit-Adresse RETLW m_display_l ; Joystick Positionsdisplay, links

RETLW m_LJoyX_adr ; Joystick links, x-Achse - Digit-Adresse RETLW m_display_c ; Joystick Positionsdisplay, recht&links... ; mittlere LEDs

END

## 3.2 Flussdiagramme





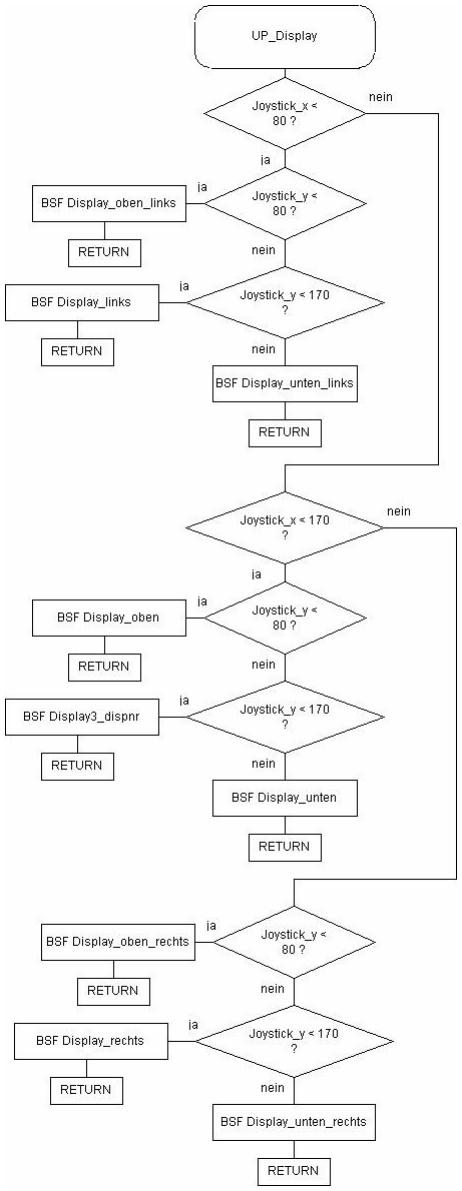
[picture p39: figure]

## 4.0 Bilanz

Durch die Probleme, die ich in der ersten Zeit der Projektphase nicht lösen konnte, befürchtete ich, dass das Projekt nicht erfolgreich abgeschlossen werden könnte.

### Trotzdem versuchte ich weiterhin die Programmierlösung zu finden. Als der Fehler

gefunden und beseitigt war, ging es endlich weiter.

Ich hatte mir schon im Voraus überlegt, was ich mit dem Controller alles steuern könnte. Da mein Klassenkamerad aber zu diesem Zeitpunkt Probleme mit dem MAX7219 Display Treiber hatte und mich um Hilfe fragte, wurde mir bewusst, dass die Ansteuerung dieses Bausteins dem Playstation-Controller ähnelt. So wurde vorübergehend aus meinem Projektvorschlag (Anzeige von 8 Tastenzuständen) eine LED Display Treiber geregelte 16 Tasten-Zustandsanzeige mit Positionsanzeige der

Joysticks.

### Leider konnte ich die Umsetzung dieser Projekterweiterung nicht auf einer Platine fertig stellen. Daher hab ich mich entschlossen die Platine ätzen zu lassen, was sich später als teurer Fehler herausgestellt hat: die Platine funktioniert nur bedingt. Aus

diesem Grund bin ich auf mein ursprüngliches Projektvorhaben zurückgekommen.

### Dennoch kann ich mit Bestimmtheit sagen, dass ich durch diesen Projektablauf einiges hinzugelernt habe (wie man auch auf dem Video erkennen kann). Trotz aller

Schwierigkeiten hat mir die Arbeit mit dem Projekt viel Spaß gemacht.

## 5.0 Quellen

### Playstation Controller: http://www.parallax.com/html_pages/resources/catapps/cat_ps.asp http://www.geocities.com/digitan000/Hardware/22/e22_page.html http://www.hardwarebook.info/Sony_Playstation_Controller_Port http://users.ece.gatech.edu/~hamblen/489X/f04proj/USB_PSX/psx_protocol.html

### indirekte Adressierung: http://www.roboternetz.de/phpBB2/viewtopic.php?p=264376#264376 http://www.sprut.de/electronic/pic/grund/adress.htm#indirekt

### Sonstige: http://www.staff.uni-bayreuth.de/~btp918/cmt2004/PIC/Handout/06%20Fortgeschrittene%20Programmiert echniken.pdf http://www.piclist.com/techref/microchip/compcon.htm

### Platine: http://platinen-design.de/ - die angefertigte Platine ist nicht funktionsfähig! - die Bohrungen waren zu klein - die Platine wurde zu spät gesendet - die Kontaktfläche um die Bohrungen sind zu dünn

## 5.1 Versicherung der Eigenleistung

### Hiermit versichere ich, Aryan Layes, dass ich die vorliegende Projektarbeit selbstständig, ohne fremde Hilfe und nur mit den angegebenen Hilfsmittel erstellt

habe.

### Datum, Unterschrift: _______________________________________________

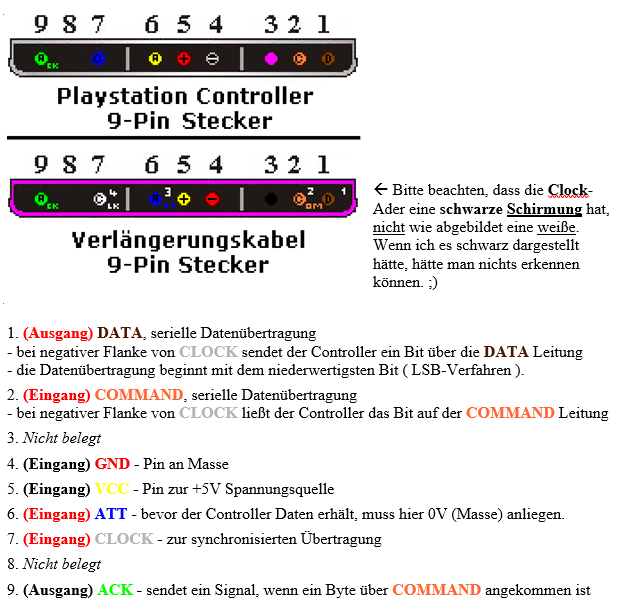
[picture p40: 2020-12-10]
assets/ps2-pinout.PNG

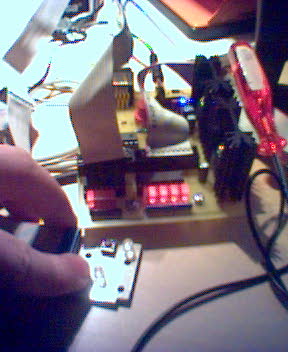
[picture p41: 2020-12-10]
pics/Bild_3.jpg

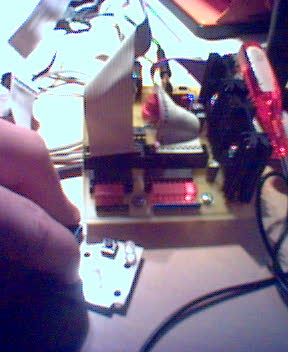
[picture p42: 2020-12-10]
pics/Bild_2.jpg

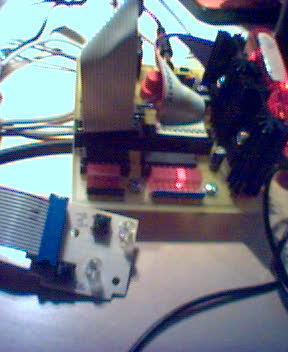
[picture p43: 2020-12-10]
pics/Bild_4.jpg

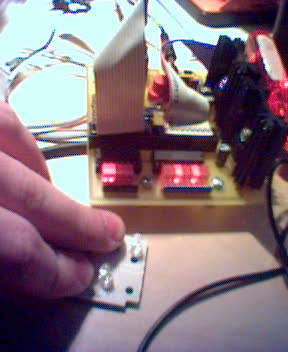
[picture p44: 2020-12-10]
pics/Bild_5.jpg

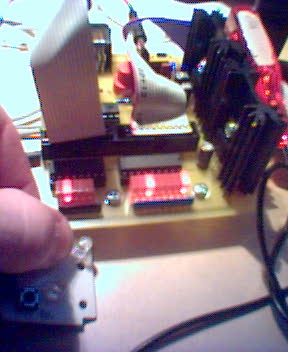
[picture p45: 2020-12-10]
pics/Bild_.jpg

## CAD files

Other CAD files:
source/ps2_joystick_simulator/ps2_controller.obj
source/ps2_joystick_simulator/unt_controller.obj

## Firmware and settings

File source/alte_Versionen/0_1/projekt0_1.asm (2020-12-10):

; *******************************************************
; * Projekt06.asm - Playstation Controller an PIC16F84A *
; *******************************************************
;
;	KOMMT NOCH.... 
;
;
; **************************************************************
; *			Changelog 0_1			*
; **************************************************************
;
; UP_wait250khz hinzugefügt
; UP_wait05s hinzugefügt
;
; main neu aufgebaut um Programmablauf per LED's anzeigen zu lassen
;
;
;***************************************************************************
;* Bestimmung des Prozessortyps für den Assembler und das Programmiergerät *
;***************************************************************************

		LIST p=16F84A


;*******************************************************************
;* Includedatei für den 16F84A einbinden (vordef. Reg. und Konst.) *
;*******************************************************************

		#include <p16f84A.INC>

; Diese Datei enthält Vordefinitionen für wichtige Register und Konstanten.
; (Z.B. gibt es die Konstante PORTB mit der sich ohne Angabe der
; absoluten Adresse H'0006' der Port B des Prozessors ansprechen lässt)


;*********************************************************
;* Konfigurationseinstellungen für IC-Prog vordefinieren *
;*********************************************************

		__CONFIG _PWRTE_ON & _CP_OFF & _HS_OSC & _WDT_OFF

; Hier werden verschiedene Prozessoreigenschaften festgelegt:
; _PWRTE_ON schaltet den Power Up Timer ein, d.h. der Prozessor wartet nach
;           dem Einschalten ca. 70ms mit dem Programmstart, um sicher zu sein,
;           dass alle angeschlossene Peripherie bereit ist.
; _CP_OFF schaltet die Code-Protection des Prozesors aus. Damit ist das im Prozessor
;        befindliche Programm jederzeit auslesbar und überschreibbar.
; _HS_OSC spezifiziert einen Quarzoszillator (Highspeed) als Zeitbasis für den Prozessor.
; _WDT_OFF schaltet den Watchdog-Timer des Prozesors aus.


;***********************************
;* Register / Variablen  festlegen *
;***********************************
; hier werden Adressen von Registern / Variablen festgelegt. Diese werden beginnend
; mit der Adresse H'20' aufsteigend vergeben.


	CBLOCK	H'20'
		zaehler_in	;Zaehler innere Schleife
		zaehler_mid	;Zaehler mittlere Schleife
		zaehler_out	;Zaehler aeussere Schleife
		
		cnt_get_btn_stats	;Get_Btn_Stats Schleife
		
		wait250khz	;250kHz zaehler
		
		wait05s
		wait05s_1
		wait05s_2
		

	ENDC
	
	in_cnt		EQU D'0'		;Startwert inner Schleife
	mid_cnt		EQU D'0'		;Startwert mittlere ""
	out_cnt		EQU D'1'		;Startwert äussere ""
	
	get_btn_stats_cnt	EQU D'7'		;Startwert Get_Btn_Stats Schleife


;************************
;* Konstanten festlegen * 
;************************



; ***********************************************************************
; * Definition von einzelnen Bits in einem Register / in einer Variable *
; ***********************************************************************

;#####################################################################
#DEFINE	e_data		PORTA, 0		; Data		Eingang
#DEFINE	a_command	PORTA, 1		; Command	Ausgang
#DEFINE	a_clock		PORTA, 2		; Takt		Ausgang
#DEFINE	a_att		PORTA, 3		; ATT		Ausgang
;#####################################################################
#DEFINE	a_test		PORTB, 0		; Tets LED	Ausgang
;#####################################################################
#DEFINE	a1		PORTB, 0		; BCD-Decoder	Ausgang
#DEFINE	b1		PORTB, 1		; BCD-Decoder	Ausgang
#DEFINE	c1		PORTB, 2		; BCD-Decoder	Ausgang
#DEFINE	d1		PORTB, 3		; BCD-Decoder	Ausgang
;#####################################################################
#DEFINE	a2		PORTB, 4		; BCD-Decoder	Ausgang
#DEFINE	b2		PORTB, 5		; BCD-Decoder	Ausgang
#DEFINE	c2		PORTB, 6		; BCD-Decoder	Ausgang
#DEFINE	d2		PORTB, 7		; BCD-Decoder	Ausgang
;#####################################################################
#DEFINE	bank1		STATUS, RP0
;#####################################################################



; In diesem Beispiel steht das Wort ir_sensor für Bit 0 von Port A und das Wort motor
; für das Bit 0 von Port B.


;*****************
;* Programmstart *
;*****************

	ORG	H'00'		; Das Programm wird ab Speicherstelle 0 in den Speicher geschrieben
	GOTO	init		; Springe zur Grundinitialisierung der Ports A und B


;*******************
;* Initialisierung *
;*******************

init	BSF	bank1		; wechsle zu Registerbank 1 (spezielle Register)

	MOVLW	B'00000001'
	MOVWF	TRISA		; RA0 Eingang (RA1 bis RA3 sind Ausgänge)
	MOVLW	B'00000000'
	MOVWF	TRISB		; RB0 bis RB7 sind Ausgänge
	
	BCF	bank1		; wechsle zu Registerbank 0 (normaler Speicherbereich)
        
	CLRF	PORTA		; Port A löschen
	CLRF	PORTB		; Port B löschen
        
; Die Register TRISA und TRISB legen fest, welche Bits in den jeweiligen Ports Ein- bzw.
; Ausgänge sind. Eine '1' an der entsprechenden Stelle setzt das Bit des Ports als Ein-
; gang eine '0' setzt das Bit als Ausgang.



;*****************
;* Hauptprogramm *
;*****************

;#######################################################################
;#DEFINE	e_data		PORTA, 0		; Data		Eingang #
;#DEFINE	a_command	PORTA, 1		; Command	Ausgang #
;#DEFINE	a_clock		PORTA, 2		; Takt		Ausgang #
;#DEFINE	a_att		PORTA, 3		; ATT		Ausgang #
;#######################################################################
;#DEFINE	a_test		PORTB, 0		; Tets LED	Ausgang #
;#######################################################################
;#DEFINE	a1		PORTB, 0		; BCD-Decoder	Ausgang #
;#DEFINE	b1		PORTB, 1		; BCD-Decoder	Ausgang #
;#DEFINE	c1		PORTB, 2		; BCD-Decoder	Ausgang #
;#DEFINE	d1		PORTB, 3		; BCD-Decoder	Ausgang #
;#######################################################################
;#DEFINE	a2		PORTB, 4		; BCD-Decoder	Ausgang #
;#DEFINE	b2		PORTB, 5		; BCD-Decoder	Ausgang #
;#DEFINE	c2		PORTB, 6		; BCD-Decoder	Ausgang #
;#DEFINE	d2		PORTB, 7		; BCD-Decoder	Ausgang #
;#######################################################################


main	
	CALL	UP_wait05s
	BSF	a_att			;Controller ignoriert alle Daten
		
	BSF	a1;;;;;;;;;				
	CALL	UP_wait05s				
	CALL	UP_Start			;H'01'
	BCF	a1;;;;;;;;;
	
	BSF	b1;;;;;;;;;	
	CALL	UP_wait05s
	CALL	UP_GetType		;H'42'
	BCF	b1;;;;;;;;;
	
	BSF	c1;;;;;;;;;
	CALL	UP_wait05s
	CALL	UP_Status		;H'00'
	BCF	c1;;;;;;;;;
	
	BSF	d1;;;;;;;;;
	CALL	UP_wait05s
	CALL	UP_linke_btns		;H'00'
	BCF	d1;;;;;;;;;
	
	BSF	a2;;;;;;;;;
	CALL	UP_wait05s
	CALL	UP_rechte_btns		;H'00'
	BCF	a2;;;;;;;;;
	
	BSF	b2;;;;;;;;;
	CALL	UP_wait05s
	CALL	UP_sende0		;#########################
	CALL	UP_sende0		;Hier kommen die Joysticks
	CALL	UP_sende0		;die abgefragt werden aber
	CALL	UP_sende0		;nicht gespeichert
	BCF	b2;;;;;;;;;	




	GOTO	main


;******************
;* Unterprogramme *
;******************
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
